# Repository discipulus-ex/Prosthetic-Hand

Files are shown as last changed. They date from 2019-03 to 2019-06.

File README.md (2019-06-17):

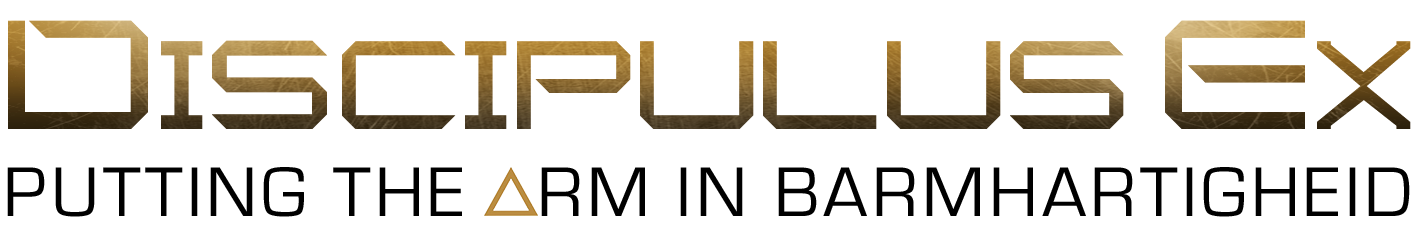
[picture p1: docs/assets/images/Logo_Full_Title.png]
Discipulus-Ex


# Discipulus-Ex: Prosthetic Hand
> A 3D-printed partial hand prosthesis using Arduino and OYMotion.

[The Prosthetic Hand:]()

---

## Table of Contents
- [Installation](#installation)
- [Features](#features)
- [Contributing](#contributing)
- [Team](#team)
- [Support](#support)
- [License](#license)

---

## Installation
Coming soon!

### Clone
Clone this repo to your local machine using:
```
$ git clone https://github.com/discipulus-ex/Prosthetic-Hand.git
```

---

## Features
Coming soon!

## Usage
Coming soon!

## Documentation
Coming soon!

---

## Contributing
### Step 1
- **Option 1**
  - Fork this repo!
- **Option 2**
  - Clone this repo to your local machine using:
    ```
    $ git clone https://github.com/discipulus-ex/Prosthetic-Hand.git
    ```
### Step 2
- **HACK AWAY!**

### Step 3
- Create a new pull request using <a href="https://github.com/discipulus-ex/Prosthetic-Hand/compare/" target="_blank">`https://github.com/discipulus-ex/Prosthetic-Hand/compare/`</a>

---

## Team
| <a href="https://discipulusex.nl/" target="_blank">**DDuunk**</a>  | <a href="https://discipulusex.nl/" target="_blank">**BeFunk**</a> | <a href="https://discipulusex.nl/" target="_blank">**Ghoris0127**</a> |
| :---: |:---:| :---:|
| DDuunk (https://discipulusex.nl/) | BeFunk (https://discipulusex.nl/) | Ghoris0127 (https://discipulusex.nl/) |
| <a href="http://github.com/DDuunk" target="_blank">`github.com/DDuunk`</a> | <a href="http://github.com/BeFunk" target="_blank">`github.com/BeFunk`</a> | <a href="https://github.com/Ghoris0127" target="_blank">`github.com/Ghoris0127`</a> |

---

## Support
Reach us out at:

- Website at <a href="https://discipulusex.nl/" target="_blank">`discipulusex.nl`</a>

---

## License


- **[MIT license](http://opensource.org/licenses/mit-license.php)**
- Copyright 2019 © <a href="https://discipulusex.nl/" target="_blank">Discipulus-Ex</a>.

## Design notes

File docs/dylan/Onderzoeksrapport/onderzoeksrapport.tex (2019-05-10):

\documentclass[11pt, a4paper]{article}
\usepackage[english]{babel}
\usepackage[utf8]{inputenc}
\usepackage{hyperref}
\usepackage{graphicx}
\usepackage{array}
\usepackage{enumitem}
\usepackage{pifont}
\usepackage{threeparttable}
\usepackage{amsmath}
\usepackage{booktabs}
\usepackage{fancyhdr}
\usepackage{pdflscape}

\renewcommand{\arraystretch}{1.5}

\graphicspath{ {./images/} }
\bibliographystyle{plain}

\title{ \Huge{Research report: \\ Prosthetic hand} \\ \vspace{1cm} \normalsize{\textit{First iteration}}} 
\author{Written by: \\ Dylan Duunk \textit{(0948392)} \\ \textit{Discipulus-Ex} 
\vspace{1cm} \\
Written for: \\ Ornella Schavemaker-Piva, \\ Wouter Volders \& \\ Nadine van Dormolen}
\vspace{1cm}
\date{12th April 2019}

\begin{document}

\begin{titlepage}
    \maketitle
\end{titlepage}

\pagenumbering{roman}

\newpage
 
\begin{abstract}
    \noindent
    Contemporary prostheses have advanced significantly the last few years.
    Previously, prostheses were quite expensive, nowadays one can 3D print a open-source prosthesis design.
    Unfortunately those designs are mostly made for below-elbow and above-elbow amputees.
    Our audience are people with a partial hand.
    With a partial hand prosthesis you also have to take the length of the user's arm in account.
    This makes it difficult to design prostheses for them.
    \\ \\
    So the research question is as follows: 
    \emph{
        \vspace{5pt}
        \begin{center}
            ``How to make an efficient design for a partial hand prosthesis and which parts are involved in making such a design?''
        \end{center}
        \vspace{5pt}
    }
    
    \noindent
    In this research report I will describe the different factors that play a role in making a prosthesis design, such as material choice and comfort.
    Furthermore I will describe the design I came up with.
\end{abstract}    

\newpage
\tableofcontents
\newpage
\pagenumbering{arabic}

\pagestyle{fancy}
\fancyhf{}
\rhead{Dylan Duunk}
\lhead{Research report: Prosthetic hand}
\rfoot{\thepage}

\section{Introduction}
Prostheses have advanced significantly in their functional capabilities and appearances over the past few years.
The latest trends in fabrication are elevating prosthetic comfort, function and appearance for thousands of prosthesis users.
But most of the higher-end prostheses are way to expensive for most people, while more and more people are eligible for prostheses.
\\ \\
With the latest technology of 3D printing and greater access to a 3D printer, the production of prostheses has become a lot easier and cheaper.
With the open source community of 3D printing, everyone with access to a 3D printer can make a prosthesis for themselves or for others.
\\ \\
Unfortunately for people with a partial hand, there are barely any designs for partial hand prostheses.
Most of these designs are body-powered prostheses or finger prostheses.
\\ \\
In this document, I will assess a variety of materials based on their suitability for prostheses whilst maintaining a comfortable fit and I show my design for a partial hand prosthesis and the idea behind it.

\section{Preliminary investigation}
One of the earliest records of a prosthetic hand was described n 77 AD by Roman scholar Pliny the Elder in his encyclopedia \textit{Naturalis Historia}\cite{natural_history}.
After losing a hand in the Second Punic War (218-201 BC), Marcus Sergius, a Roman general, received a prosthesis that enabled him to return successfully to battle and continue his position as a general.
\\ \\ 
Among the most famous example of an early hand prosthesis was the iron hand of German knight G\"otz von Berlichtingen \cite{historical_prostheses}.
After G\"otz lost his hand during the Siege of Landshut (circa 1505) in Bavaria, an artisan fashioned him an iron hand with digits that could be flexed and extended passively at finger joints (Figure \ref{fig:GotzProsthesis}).
Due to its weight, the device needed to be attached to G\"otz armour rather than his arm. 
\\
\begin{figure}[h]
    \centering
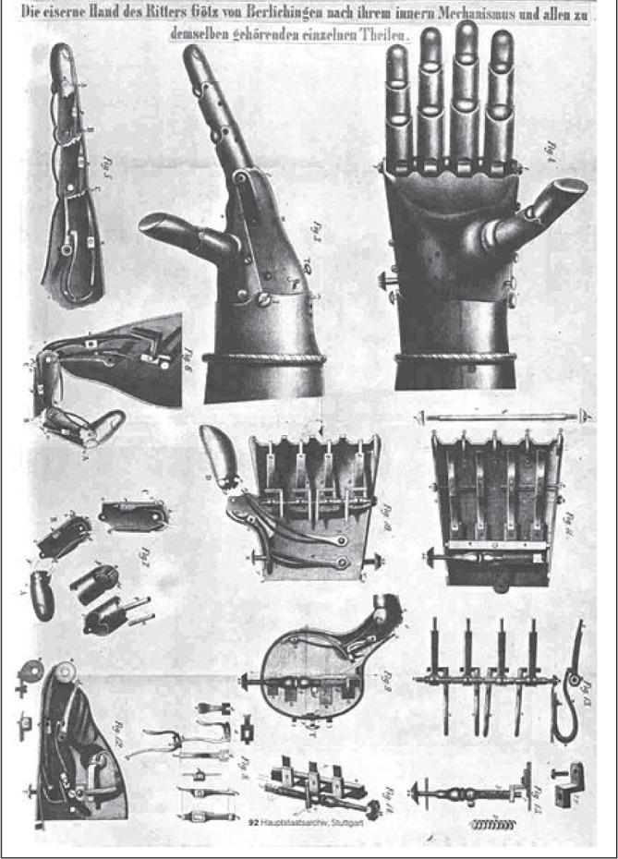
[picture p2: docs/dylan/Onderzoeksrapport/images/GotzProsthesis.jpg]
    
    \caption{Illustration of the numerous components of G\"otz's medieval hand prosthesis.}
    \label{fig:GotzProsthesis}
\end{figure}

\newpage

\noindent 
The concept of an body-powered upper limb prosthesis was pioneered by German dentist Peter Baliff in 1818 \cite{history_of_arm_amputation}.
Using transmission of tension through leather straps.
Baliff's device was opperated by the use of the trunk and shoulder girdle to elicit motion in the device.
\\ \\
In 1916, German surgeon Dr Ferdinand Sauerbruch described his prosthetic design with digits controlled by transmission of upper arm muscle movements (Figure \ref{fig:SauerbrunchProsthesis}) \cite{sauerbrunch}.
Unfortunately, due to the high cost of production, few individuals were able to afford the device.
\\
\begin{figure}[h]
    \centering
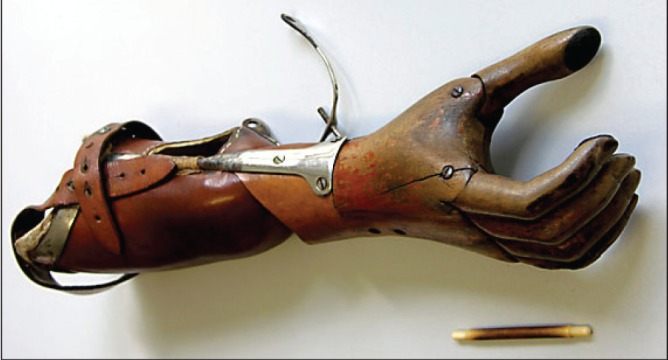
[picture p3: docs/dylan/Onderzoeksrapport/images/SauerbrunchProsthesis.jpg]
    
    \caption{Sauerbrunch's prosthetic hand design. Video captures of patients using the prosthesis to perform various activities may by viewed at \url{http://vlp.mpiwg-berlin.mpg.de/library/data/lit38416}}
    \label{fig:SauerbrunchProsthesis}
\end{figure} 

\noindent
In 1948, the Bowden cable body-powered prosthesis was introduced, replacing bulky straps with a sleek, sturdy cable.
Today's body-powered prostheses are essentially adaptations of the Bowden design (Figure \ref{fig:BowdenProsthesis}). 
Durable, portable and relatively affordable, body-powered prostheses allow the user an impressive range of motion, speed and force in operating a terminal device.
This design works by changing the tension in a cable via shoulder and body movements.
The design allows the ability to use both hands simultaneously, rather that requiring a healthy hand to control the prosthesis.
Furthermore, the user is able to predict and adjust the position of the prosthesis without visual feedback.
Although prolonged wearing can be uncomfortable, complicated motor tasks are limited and appearance is not human-like, body-powered prostheses are widely used.
\\
\begin{figure}[h]
    \centering
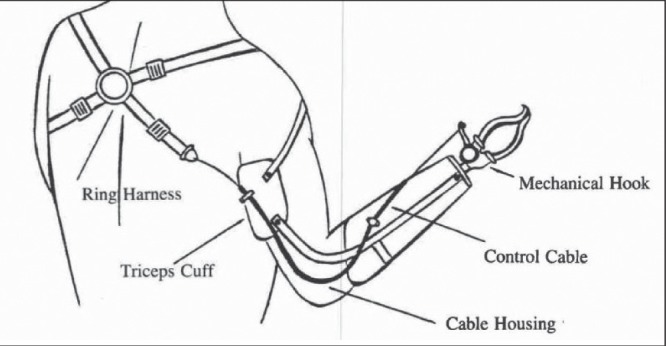
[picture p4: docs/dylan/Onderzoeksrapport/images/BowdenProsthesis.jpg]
    
    \caption{Bowden cable body powered prosthesis.}
    \label{fig:BowdenProsthesis}
\end{figure} 

\noindent
In 1919, a German book titled \textit{Ersatzglieder un Arbeitshilfen (Limb Substitutes and Work Aids)} contained conceptual designs for the first externally powered prostheses, using pneumatic and electric power sources (Figure \ref{fig:PrebluftHand}).
Unfortunately, these revolutionary designs were to complex for their time.
\\
\begin{figure}[h]
    \centering
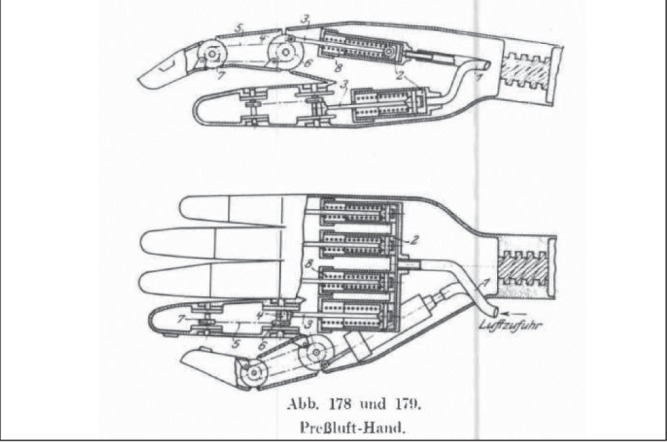
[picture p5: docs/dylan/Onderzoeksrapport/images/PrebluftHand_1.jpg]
    
    \caption{Early compressed gas-powered prosthetic hand from 1919 German book \textit{Ersatzglieder un Arbeitshilfen (Limb Substitutes and Work Aids)}.}
    \label{fig:PrebluftHand}
\end{figure} 

\noindent
The first myoelectric prosthesis was created in 1948 by Reinhold Reiter, a physics student at Munich University (Munich, Germany).
This device amplifies surface electromyography (EMG) potentials to power motorized parts.
\\ \\
The first clinically significant myoelectric prosthesis was unveiled by Russian scientist Alexander Kobrinski in 1960.
With the use of transistors he managed to reduce bulk and allowed portability of the prosthesis.
This prosthesis had numerous problems: it was heavy, movement was slow, pinch force was weak, wire connections were susceptible to damage and electrical interference compromised reliability \cite{myoelectric}.  

\newpage

\noindent
Nowadays myoelectric prostheses are a common option for amputees. 
They improved drastically in design, weight, power and cost.
In addition, signal detection is noninvasive on the skin surface and prosthetic movement is comparable with a normal limb.

\begin{figure}[h]
    \centering
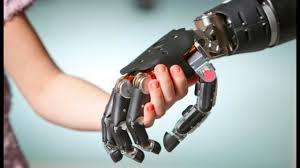
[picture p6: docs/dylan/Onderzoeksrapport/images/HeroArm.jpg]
    
    \caption{The Hero Arm, the world's first medically certified 3D-printed bionic arm, with multi-grip functionality and empowering aesthetics. \textit{Developed by OpenBionics} \url{https://openbionics.com/hero-arm/}}
    \label{fig:HeroArm}
\end{figure}    

\noindent
The problem with contemporary myoelectric prostheses is that they are primarily made for below-elbow and above-elbow amputees.
For our version we need to make a prosthetic hand for someone with a partial hand and therefore cannot use these common myoelectric prostheses.
So we need to come up with our own design.
\\ \\
This design needs to incorporate a lightweight material and has to be comfortable to use.

\section{Methodology}
My research consists of three parts: material, comfort and a prototype design incorporating the two previous aspects.
\\
These are my research methods for each part:
\begin{description}[align=left]
    \item[Material] Review a variety of commonly used materials for prostheses and compare them to each other.
    \item[Comfort] Research which factors play a role in comfort.
    \item[Prototype design] Experiment with various designs.
\end{description}    

\section{Results}
These are the results of my research:
\subsection{Materials} \label{materials}
Material choice plays a major role in prostheses.
Prostheses must be both strong and lightweight, they must be able to withstand the extensive use of the owner without obstructing there range of motion.
\\
Below I will review a variety of materials for our prosthetic hand.

\subsubsection{Plastic}
PLA and ABS are 2 of the most common FDM (Fused deposition modeling) desktop printing materials.
Both materials are thermoplastics, meaning they become pliable or moldable at a certain elevated temperature and solidifies upon cooling.
Via the FDM process, both materials are melted and then extruded trough a nozzle to build up the layers that create a final part.
\\ \\
Table \ref{tab:pla-abs} below compares the main properties between PLA \& ABS:

\begin{table}[ht]
    \centering
    \begin{threeparttable}
        \begin{tabular}[t]{>{\bfseries}l l l}
            \toprule
            Properties\tnote{1} & \textbf{PLA} & \textbf{ABS} \\
            \midrule
            Density & $1.3 g/cm^3$ & $1.0 - 1.4 g/cm^3$ \\
            Elongation & 6\% & 3.5-50\% \\ %https://en.wikipedia.org/wiki/Deformation_(mechanics)#Stretch_ratio
            Flexural Modulus & 4GPa & 2.1-7.6 GPa \\ %https://en.wikipedia.org/wiki/Flexural_modulus
            Melting Point & $160\,^{\circ}{\rm C}$ & N/A (amorphous) \\
            Biodegradable & Yes, under the correct conditions & No \\
            Glass Transition Temperature & $60\,^{\circ}{\rm C}$ & $105\,^{\circ}{\rm C}$ \\ %https://en.wikipedia.org/wiki/Glass_transition
            \bottomrule
        \end{tabular}
        \caption{Comparing PLA with ABS}
        \label{tab:pla-abs}
        \begin{tablenotes}
            \item[1] \textit{Sourced from MakeItFrom \cite{MakeItFrom}}
        \end{tablenotes}    
    \end{threeparttable}    
\end{table}

\subsubsection{Silicone}
Silicone is a dynamic material that moves with the body while simultaneously offering 
an enhanced grip on the residual limb and improved suspension of the prosthesis.
Silicone is mostly used in realistic looking prosthetics and for mold making.
\\ \\ 
Table \ref{tab:silicone-properties} below gives the main properties of silicone:

\begin{table}[ht]
    \centering
    \begin{threeparttable}
        \begin{tabular}[t]{>{\bfseries}l l}
            \toprule
            Properties\tnote{1} & \textbf{Silicone plastic}  \\
            \midrule
            Density & $1.9 g/cm^3$  \\
            Elastic Modulus & 9.0 GPa \\ %https://en.wikipedia.org/wiki/Elastic_modulus
            Max. Temperature: Decomposition & $480\,^{\circ}{\rm C}$  \\
            Biodegradable & No  \\
            Glass Transition Temperature & $200\,^{\circ}{\rm C}$  \\ %https://en.wikipedia.org/wiki/Glass_transition
            \bottomrule
        \end{tabular}
        \caption{Properties silicone plastic}
        \label{tab:silicone-properties}
        \begin{tablenotes}
            \item[1] \textit{Sourced from MakeItFrom \cite{MakeItFrom}}
        \end{tablenotes}    
    \end{threeparttable}    
\end{table}

\subsubsection{Carbon Fiber}
Carbon fiber reinforced plastic (CFRP), is an extremely strong and light fiber-reinforced plastic which contains carbon fibers.
Carbon fiber is often used in prosthetics, sports equipment, aerospace and wherever the high strength-to-weight ratio and stiffness from carbon fiber are required.
CFRPs are composite materials.
In this case the composite consists of two parts: a matrix and a reinforcement.
In this case the reinforcement is carbon fiber, which provides the strength.
The matix is usually a polymer resin, such as epoxy, to bind the reinforcements together.
This makes the material properties depend on those distinct elements.

\subsubsection{Metal}
Alloys containing titanium are known for their high strength, lightweight, and exceptional corrosion resistance.
Despite being as strong as steel, titanium is about 40\% lighter in weight.
Titanium is also formidable in its resistance to corrosion by both water and chemical media.
\\
Because titanium has a low modulus of elasticity that means titanium is not also very flexible, but returns to its original shape after bending.
\\ \\
Aluminium is a very light metal with a specific weight of $2.7 g/cm^3$, about a third that of steel.
Its strength can be adapted to the apllication required by modifying the composition of its alloys.
Aluminium naturally generates a protective oxide coating and is highly corrosion resistant which can be further imporeved by different types of surface treatments. 
This is particularly usefull for applications where protection and conservation are required.

\subsubsection{Morphological chart}

\begin{table}[ht]
    \centering
    \begin{threeparttable}
        \begin{tabular}[t]{>{\bfseries}l c c c c c c}
            \toprule
            & \textbf{PLA} & \textbf{ABS} & \textbf{Silicone} & \textbf{Carbon} & \textbf{Titanium\tnote{1}} & \textbf{Aluminium\tnote{1}}  \\
            \midrule
            Easy of use & \ding{72}\ding{72}\ding{72}\ding{72}\ding{72} & \ding{72}\ding{72}\ding{72}\ding{72}\ding{73} & \ding{72}\ding{72}\ding{72}\ding{73}\ding{73} & \ding{72}\ding{72}\ding{73}\ding{73}\ding{73} & \ding{72}\ding{73}\ding{73}\ding{73}\ding{73} & \ding{72}\ding{72}\ding{73}\ding{73}\ding{73} \\
            Strength & \ding{72}\ding{72}\ding{73}\ding{73}\ding{73} & \ding{72}\ding{72}\ding{72}\ding{73}\ding{73} & \ding{72}\ding{72}\ding{72}\ding{72}\ding{73} & \ding{72}\ding{72}\ding{72}\ding{72}\ding{72} & \ding{72}\ding{72}\ding{72}\ding{72}\ding{72} & \ding{72}\ding{72}\ding{72}\ding{72}\ding{72} \\
            Weight\tnote{2} & \ding{72}\ding{72}\ding{72}\ding{72}\ding{72} & \ding{72}\ding{72}\ding{72}\ding{72}\ding{72}  & \ding{72}\ding{72}\ding{72}\ding{72}\ding{72} & \ding{72}\ding{72}\ding{72}\ding{72}\ding{72} & \ding{72}\ding{72}\ding{72}\ding{72}\ding{72} & \ding{72}\ding{72}\ding{72}\ding{72}\ding{72}  \\
            Elastic Modulus & \ding{72}\ding{72}\ding{73}\ding{73}\ding{73} & \ding{72}\ding{72}\ding{72}\ding{73}\ding{73} & \ding{72}\ding{72}\ding{72}\ding{72}\ding{72} & \ding{72}\ding{72}\ding{72}\ding{73}\ding{73} & \ding{72}\ding{72}\ding{72}\ding{72}\ding{72} & \ding{72}\ding{72}\ding{72}\ding{73}\ding{73} \\
            Price & \ding{72}\ding{72}\ding{72}\ding{72}\ding{72} & \ding{72}\ding{72}\ding{72}\ding{72}\ding{72} & \ding{72}\ding{72}\ding{72}\ding{72}\ding{73} & \ding{72}\ding{72}\ding{73}\ding{73}\ding{73} & \ding{72}\ding{73}\ding{73}\ding{73}\ding{73} & \ding{72}\ding{72}\ding{72}\ding{73}\ding{73} \\
            Usability\tnote{3} & \ding{72}\ding{72}\ding{72}\ding{72}\ding{72} & \ding{72}\ding{72}\ding{72}\ding{72}\ding{73} & \ding{72}\ding{72}\ding{72}\ding{73}\ding{73} & \ding{72}\ding{73}\ding{73}\ding{73}\ding{73} & \ding{73}\ding{73}\ding{73}\ding{73}\ding{73} & \ding{72}\ding{73}\ding{73}\ding{73}\ding{73} \\
            \bottomrule
        \end{tabular}
        \caption{Materials Morphological Chart}
        \label{tab:morphchart-material}  
        \begin{tablenotes}
            \item[] These values in this Morphological Chart are based on eachother.
            \item[1] The material properties of these materials can vary based on the alloys used.
            \item[2] Weight is based on how lightweight the material is.
            \item[3] Usability in this case is based on how usefull this material will be for our prototype.  
        \end{tablenotes}    
    \end{threeparttable}   
\end{table}

\subsection{Comfort}
Comfort is an important factor for prostheses.
The prostheses must be an addition for the user, so that the user benefits of the prosthetic instead of being a chore.
Ideally the user shouldn't notice that a prosthesis is present.
This makes the user feel like a normal person and that the prosthesis is part of the body.
\\
Below I will describe which factors play a role in the comfort of prostheses.

\begin{description}[align=left]
    \item[Weight] The user must be able to wear the prosthesis for long periods of time in order to be usefull, this is why the prosthesis must be lightweight.
                  Otherwise the user has to carry the have load of the prosthesis and is therefore not sufficient.
    \item[Range of motion] The user must be able to have a relatively free range of motion, so that the user doesn't feel restricted.                       
    \item[Fit] The prosthesis must be securly fit to the user without impending the bloodflow.
               The fit shouldn't be to loose either, otherwise it will slip around all the time. 
    \item[Breathability] Because the user is wearing the prosthesis for longer periods of time, the user's skin needs to be able to freely breathe.   
    \item[Aesthetics] For some people the prosthesis my not stand out.
                      The attention some people get with a prosthesis may be annoing sometimes. 
\end{description}

\subsection{Prototype Design}
\textit{*Note: So far, the prototype only consists of the connection between my (Dylan) arm and a potential hand}

\subsubsection{First Prototype}
For the first prototype I wanted to make a casing for my forearm.
Because I didn't have access to a 3D scanner I had to come up with another solution to convert my drawings (Figure \ref{fig:ConceptPrototype1}) into a 3D model.
So I took measurements of my arm at different points, and seperated them into circles.
With these circles I moddeled around those circles in Fusion 360 and came up with this design (Figure \ref{fig:Prototype1Mechanical}). 
\\ \\
See table \ref{tab:FirstPrototypeProsCons} for the pros and cons of the first prototype.
\begin{table}[ht]
    \centering
    \begin{tabular}[t]{p{6cm} p{6cm}}
    \toprule
    \textbf{Pros} & \textbf{Cons} \\
    \midrule
    Thickness of the prototype is good. & For a someone with a partial hand this design is unneccessary bulky. \\
    & Design is more suitable for below-elbow amputees. \\
    & Fit was to small in diameter, which was solved by heating the prototype in hot water and reforming it. \\
    \bottomrule
    \end{tabular}
    \caption{First Prototype: Pros \& Cons}
    \label{tab:FirstPrototypeProsCons}
\end{table}

\begin{figure}[h]
    \centering
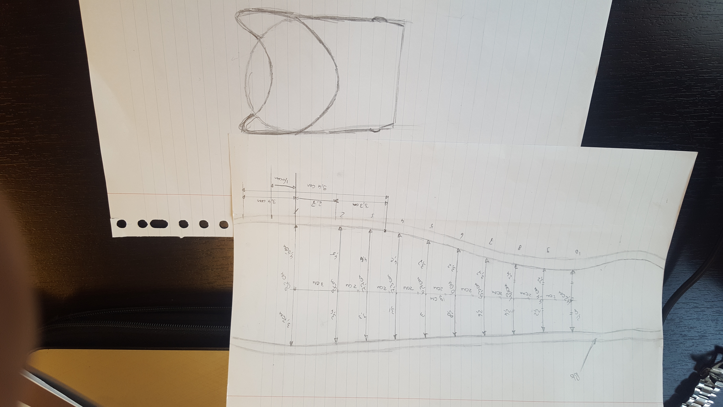
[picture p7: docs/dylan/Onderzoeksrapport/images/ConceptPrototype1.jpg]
    
    \caption{Concept drawings of the first prototype}
    \label{fig:ConceptPrototype1}
\end{figure} 

\newpage

\begin{landscape}
    \thispagestyle{empty}
    \begin{figure}[h]
        \centering
        
        \caption{Mechanical drawings for the first prototype. \textit{*Note: Measurements are mm!}}
        \label{fig:Prototype1Mechanical}
    \end{figure} 
\end{landscape}

\subsection{Second Prototype}
For the second prototype I wanted to make a casing specifically for my hand.
See figure \ref{fig:ConceptPrototype2} for my concept drawings. 
I moddeled around pictures of my hand in Fusion 360 and came up with this design (Figure \ref{fig:Prototype2Mechanical})
\\ \\
See table \ref{tab:SecondPrototypeProsCons} for the pros and cons of the second prototype.
\begin{table}[ht]
    \centering
    \begin{tabular}[t]{p{6cm} p{6cm}}
    \toprule
    \textbf{Pros} & \textbf{Cons} \\
    \midrule
    Thickness of the prototype is good. & Design is more suitable for users with a partial hand. \\
    Horizontal fit is good. & Vertical fit is in some places to loose. \\
    & Not designed for below-elbow and above-elbow amputees. \\ 
    \bottomrule
    \end{tabular}
    \caption{Second Prototype: Pros \& Cons}
    \label{tab:SecondPrototypeProsCons}
\end{table}

\begin{figure}[h]
    \centering
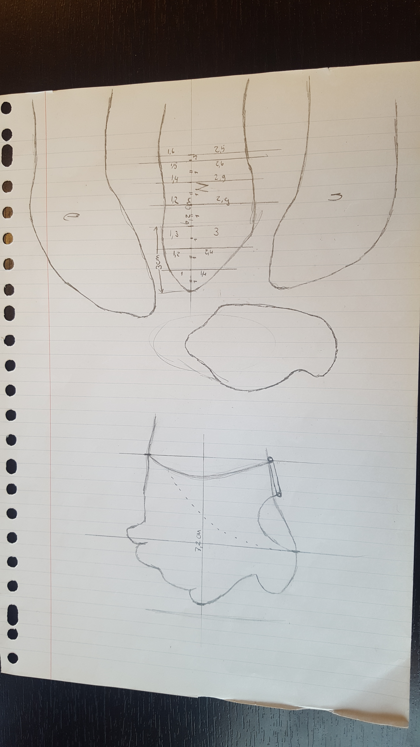
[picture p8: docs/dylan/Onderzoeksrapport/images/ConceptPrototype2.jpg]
    
    \caption{Concept drawings of the second prototype}
    \label{fig:ConceptPrototype2}
\end{figure} 

\newpage

\begin{landscape}
    \thispagestyle{empty}
    \begin{figure}[h]
        \centering
        
        \caption{Mechanical drawings for the second prototype. \textit{*Note: Some dimmensions could not be given and measurements are mm!}}
        \label{fig:Prototype2Mechanical}
    \end{figure} 
\end{landscape}

\subsection{Third Prototype}
For the third prototype I adjusted the fit of the second prototype and added a cutout so my hand could easily slide in .
I came up with this design (Figure \ref{fig:Prototype3Mechanical}).
\\ \\
See table \ref{tab:ThirdPrototypeProsCons} for the pros and cons of the third prototype.
\begin{table}[ht]
    \centering
    \begin{tabular}[t]{p{6cm} p{6cm}}
    \toprule
    \textbf{Pros} & \textbf{Cons} \\
    \midrule
    Thickness of the prototype is good. & A little cutout at the wrist would be nice. \\
    Fit is perfect. & Not designed for below-elbow and above-elbow amputees. \\ 
    No sharp edges. & \\
    Cutout is good. & \\
    \bottomrule
    \end{tabular}
    \caption{Third Prototype: Pros \& Cons}
    \label{tab:ThirdPrototypeProsCons}
\end{table}

\newpage

\begin{landscape}
    \thispagestyle{empty}
    \begin{figure}[h]
        \centering
        
        \caption{Mechanical drawings for the third prototype. \textit{*Note: Some dimmensions could not be given and measurements are mm!}}
        \label{fig:Prototype3Mechanical}
    \end{figure} 
\end{landscape}

\newpage

\section{Conclusion and advice}

\subsection{Material}
A combination of PLA, ABS and Silicone would be the best choice material wise. 
This is because PLA and ABS are easy to use for rapid prototyping, in a relatively short time we can put together a functional prototype.
When further developing this prototype to a product i suggest to look into replacing parts with stronger materials.
When it comes to silicone, silicone is very suitable for the grip pads.
These pads make it easier to pick up objects.

\subsection{Comfort}
These are my recommendations for improving the comfort of our prototype:
\begin{description}[align=left]
    \item[Weight] See section Materials \ref{materials} for my recommendation about materials and weight.
                  Another way to minimize weight is by using light weight electrical components. 
    \item[Range of motion] All moveable parts in the prototype should be able to move freely.
                           These parts shouldn't restrict the movements that the user has without the prosthesis.  
    \item[Fit] Make the prototype fit the users arm by giving a almost perfect fit.
    \item[Breathability] This is done by giving the part that fits the users arm some breathing holes, whilst not compromising structural integrity.
    \item[Aesthetics] This is done by keeping the design simple and modern.
\end{description}

\subsection{Prototype Design}
My recommendations for other amputees:
\textit{*Note: this does not include the general shape, because my hand isa different size.}
\begin{description}
    \item[Above-elbow] Extend the first prototype design to the upper arm.
                       Make sure the prototype can be rotated where the elbow would have been.
                       If the fit at the upper arm is not good enough maybe look into attaching the prototype to the shoulder.
    \item[Below-elbow] Extend the first prototype aswell.
                       If the fit at the lower arm is not good enough maybe look into attaching the prototype to the elbow/upper arm.
    \item[Other partial hands] For people with no fingers or "little stumps" see my recommendations for extending the current design below.
                               For people with some fingers extend the third design by cutting holes for the existing fingers.  
\end{description}

My recommendations for extending the current design are:
\begin{itemize}
    \item Extend the third prototype with a palm.
    \item Extend the palm with a connection to the fingers.
    \item Make an extension to the wrist for extra stability.
\end{itemize}

\clearpage
\addcontentsline{toc}{section}{References}
\bibliography{literature}

\end{document}

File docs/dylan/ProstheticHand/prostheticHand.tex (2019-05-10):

\documentclass[11pt, a4paper]{article}
\usepackage[english]{babel}
\usepackage[utf8]{inputenc}
\usepackage{hyperref}
\usepackage{graphicx}
\usepackage{array}
\usepackage{enumitem}
\usepackage{pifont}
\usepackage{threeparttable}
\usepackage{amsmath}
\usepackage{booktabs}
\usepackage{lipsum}

\renewcommand{\arraystretch}{1.5}

\graphicspath{ {./images/} }
\bibliographystyle{plain}

\title{\Huge{Prosthetic Hand} } 
\author{Dylan Duunk \\ \textit{Discipulus-Ex} }
\date{\today}

\begin{document}

\begin{titlepage}
    \maketitle
\end{titlepage}

\pagenumbering{roman}

% \newpage

% \begin{abstract}
%     \noindent 
%     \lipsum[1]
% \end{abstract}

\newpage
\tableofcontents
\newpage
\pagenumbering{arabic}

\section{Introduction}
Prostheses have advanced significantly in their functional capabilities and appearances over the past few years.
The latest trends in fabrication are elevating prosthetic comfort, function and appearance for thousands of prosthesis users.
But most of the higher-end prostheses are way to expensive for most people, and while more and more people are eligible for prosthesis.
\\ \\
With the latest technology of 3d printing and accessibility to a 3d printer, the production of prostheses has become a lot easier and cheaper.
With the open source community of 3d printing, everyone with access to a 3d printer can make a prosthetic for themselves.
\\ \\
In this document, I will assess a variety of materials based on their suitablility for prostheses whilst maintaining a comfortable fit. 

\section{Materials} \label{materials}
Material choice plays a major role in prostheses.
Prostheses must be both strong and lightweight, they must be able to withstand the extensive use of the owner without obstructing there range of motion.
\\
Below I will review a variety of materials for our prosthetic hand.

\subsection{Plastic}
PLA and ABS are 2 of the most common FDM (Fused deposition modeling) desktop printing materials.
Both materials are thermoplastics, meaning they become pliable or moldable at a certain elevated temperature and solidifies upon cooling.
Via the FDM process, both materials are melted and then extruded trough a nozzle to build up the layers that create a final part.
\\ \\
Table \ref{tab:pla-abs} below compares the main properties between PLA \& ABS:
\begin{table}[ht]
    \centering
    \begin{threeparttable}
        \begin{tabular}[t]{>{\bfseries}l l l}
            \toprule
            Properties\tnote{1} & \textbf{PLA} & \textbf{ABS} \\
            \midrule
            Density & $1.3 g/cm^3$ & $1.0 - 1.4 g/cm^3$ \\
            Elongation & 6\% & 3.5-50\% \\ %https://en.wikipedia.org/wiki/Deformation_(mechanics)#Stretch_ratio
            Flexural Modulus & 4GPa & 2.1-7.6 GPa \\ %https://en.wikipedia.org/wiki/Flexural_modulus
            Melting Point & $160\,^{\circ}{\rm C}$ & N/A (amorphous) \\
            Biodegradable & Yes, under the correct conditions & No \\
            Glass Transition Temperature & $60\,^{\circ}{\rm C}$ & $105\,^{\circ}{\rm C}$ \\ %https://en.wikipedia.org/wiki/Glass_transition
            \bottomrule
        \end{tabular}
        \caption{Comparing PLA with ABS}
        \label{tab:pla-abs}
        \begin{tablenotes}
            \item[1] \textit{Sourced from MakeItFrom \cite{MakeItFrom}}
        \end{tablenotes}    
    \end{threeparttable}    
\end{table}

\subsection{Silicone}
Silicone is a dynamic material that moves with the body while simultaneously offering 
an enhanced grip on the residual limb and improved suspension of the prosthesis.
Silicone is mostly used in realistic looking prosthetics and for mold making.
\\ \\ 
Table \ref{tab:silicone-properties} below gives the main properties of silicone:
\begin{table}[ht]
    \centering
    \begin{threeparttable}
        \begin{tabular}[t]{>{\bfseries}l l}
            \toprule
            Properties\tnote{1} & \textbf{Silicone plastic}  \\
            \midrule
            Density & $1.9 g/cm^3$  \\
            Elastic Modulus & 9.0 GPa \\ %https://en.wikipedia.org/wiki/Elastic_modulus
            Max. Temperature: Decomposition & $480\,^{\circ}{\rm C}$  \\
            Biodegradable & No  \\
            Glass Transition Temperature & $200\,^{\circ}{\rm C}$  \\ %https://en.wikipedia.org/wiki/Glass_transition
            \bottomrule
        \end{tabular}
        \caption{Properties silicone plastic}
        \label{tab:silicone-properties}
        \begin{tablenotes}
            \item[1] \textit{Sourced from MakeItFrom \cite{MakeItFrom}}
        \end{tablenotes}    
    \end{threeparttable}    
\end{table}

\subsection{Carbon Fiber}
Carbon fiber reinforced plastic (CFRP), is an extremely strong and light fiber-reinforced plastic which contains carbon fibers.
Carbon fiber is often used in prosthetics, sports equipment, aerospace and wherever the high strength-to-weight ratio and stiffness from carbon fiber are required.
CFRPs are composite materials.
In this case the composite consists of two parts: a matrix and a reinforcement.
In this case the reinforcement is carbon fiber, which provides the strength.
The matix is usually a polymer resin, such as epoxy, to bind the reinforcements together.
This makes the material properties depend on those distinct elements.

\subsection{Metal}
Alloys containing titanium are known for their high strength, lightweight, and exceptional corrosion resistance.
Despite being as strong as steel, titanium is about 40\% lighter in weight.
Titanium is also formidable in its resistance to corrosion by both water and chemical media.
\\
Because titanium has a low modulus of elasticity that means titanium is not also very flexible, but returns to its original shape after bending.
\\ \\
Aluminium is a very light metal with a specific weight of $2.7 g/cm^3$, about a third that of steel.
Its strength can be adapted to the apllication required by modifying the composition of its alloys.
Aluminium naturally generates a protective oxide coating and is highly corrosion resistant which can be further imporeved by different types of surface treatments. 
This is particularly usefull for applications where protection and conservation are required.

\subsection{Morphological chart}
% 0 stars 
% \ding{73}\ding{73}\ding{73}\ding{73}\ding{73}
% 1 stars 
% \ding{72}\ding{73}\ding{73}\ding{73}\ding{73} 
% 2 stars 
% \ding{72}\ding{72}\ding{73}\ding{73}\ding{73}
% 3 stars 
% \ding{72}\ding{72}\ding{72}\ding{73}\ding{73}
% 4 stars 
% \ding{72}\ding{72}\ding{72}\ding{72}\ding{73}
% 5 stars 
% \ding{72}\ding{72}\ding{72}\ding{72}\ding{72} 
\begin{table}[ht]
    \centering
    \begin{threeparttable}
        \begin{tabular}[t]{>{\bfseries}l c c c c c c}
            \toprule
            & \textbf{PLA} & \textbf{ABS} & \textbf{Silicone} & \textbf{Carbon} & \textbf{Titanium\tnote{1}} & \textbf{Aluminium\tnote{1}}  \\
            \midrule
            Easy of use & \ding{72}\ding{72}\ding{72}\ding{72}\ding{72} & \ding{72}\ding{72}\ding{72}\ding{72}\ding{73} & \ding{72}\ding{72}\ding{72}\ding{73}\ding{73} & \ding{72}\ding{72}\ding{73}\ding{73}\ding{73} & \ding{72}\ding{73}\ding{73}\ding{73}\ding{73} & \ding{72}\ding{72}\ding{73}\ding{73}\ding{73} \\
            Strength & \ding{72}\ding{72}\ding{73}\ding{73}\ding{73} & \ding{72}\ding{72}\ding{72}\ding{73}\ding{73} & \ding{72}\ding{72}\ding{72}\ding{72}\ding{73} & \ding{72}\ding{72}\ding{72}\ding{72}\ding{72} & \ding{72}\ding{72}\ding{72}\ding{72}\ding{72} & \ding{72}\ding{72}\ding{72}\ding{72}\ding{72} \\
            Weight\tnote{2} & \ding{72}\ding{72}\ding{72}\ding{72}\ding{72} & \ding{72}\ding{72}\ding{72}\ding{72}\ding{72}  & \ding{72}\ding{72}\ding{72}\ding{72}\ding{72} & \ding{72}\ding{72}\ding{72}\ding{72}\ding{72} & \ding{72}\ding{72}\ding{72}\ding{72}\ding{72} & \ding{72}\ding{72}\ding{72}\ding{72}\ding{72}  \\
            Elastic Modulus & \ding{72}\ding{72}\ding{73}\ding{73}\ding{73} & \ding{72}\ding{72}\ding{72}\ding{73}\ding{73} & \ding{72}\ding{72}\ding{72}\ding{72}\ding{72} & \ding{72}\ding{72}\ding{72}\ding{73}\ding{73} & \ding{72}\ding{72}\ding{72}\ding{72}\ding{72} & \ding{72}\ding{72}\ding{72}\ding{73}\ding{73} \\
            Price & \ding{72}\ding{72}\ding{72}\ding{72}\ding{72} & \ding{72}\ding{72}\ding{72}\ding{72}\ding{72} & \ding{72}\ding{72}\ding{72}\ding{72}\ding{73} & \ding{72}\ding{72}\ding{73}\ding{73}\ding{73} & \ding{72}\ding{73}\ding{73}\ding{73}\ding{73} & \ding{72}\ding{72}\ding{72}\ding{73}\ding{73} \\
            Usability\tnote{3} & \ding{72}\ding{72}\ding{72}\ding{72}\ding{72} & \ding{72}\ding{72}\ding{72}\ding{72}\ding{73} & \ding{72}\ding{72}\ding{72}\ding{73}\ding{73} & \ding{72}\ding{73}\ding{73}\ding{73}\ding{73} & \ding{73}\ding{73}\ding{73}\ding{73}\ding{73} & \ding{72}\ding{73}\ding{73}\ding{73}\ding{73} \\
            \bottomrule
        \end{tabular}
        \caption{Materials Morphological Chart}
        \label{tab:morphchart-material}  
        \begin{tablenotes}
            \item[] These values in this Morphological Chart are based on eachother.
            \item[1] The material properties of these materials can vary based on the alloys used.
            \item[2] Weight is based on how lightweight the material is.
            \item[3] Usability in this case is based on how usefull this material will be for our prototype.  
        \end{tablenotes}    
    \end{threeparttable}   
\end{table}

\subsection{Conclusion}
A combination of PLA, ABS and Silicone would be the best choice material wise. 
This is because PLA and ABS are easy to use for rapid prototyping, in a relatively short time we can put together a functional prototype.
When further developing this prototype to a product i suggest to look into replacing parts with stronger materials.
When it comes to silicone, silicone is very suitable for the grip pads.
These pads make it easier to pick up objects.

\section{Comfort}
Comfort is an important factor for prostheses.
The prostheses must be an addition for the user, so that the user benefits of the prosthetic instead of being a chore.
Ideally the user shouldn't notice that a prosthesis is present.
This makes the user feel like a normal person and that the prosthesis is part of the body.
\\
Below I will describe which factors play a role in the comfort of prostheses.

\begin{description}[align=left]
    \item[Weight] The user must be able to wear the prosthesis for long periods of time in order to be usefull, this is why the prosthesis must be lightweight.
                  Otherwise the user has to carry the have load of the prosthesis and is therefore not sufficient.
    \item[Range of motion] The user must be able to have a relatively free range of motion, so that the user doesn't feel restricted.                       
    \item[Fit] The prosthesis must be securly fit to the user without impending the bloodflow.
               The fit shouldn't be to loose either, otherwise it will slip around all the time. 
    \item[Breathability] Because the user is wearing the prosthesis for longer periods of time, the user's skin needs to be able to freely breathe.   
\end{description}

\subsection{Conclusion}
These are my recommendations for improving the comfort of our prototype:
\begin{description}[align=left]
    \item[Weight] See section Materials \ref{materials} for my recommendation about materials and weight.
                  Another way to minimize weight is by using light weight electrical components. 
    \item[Range of motion] All moveable parts in the prototype should be able to move freely.
                           These parts shouldn't restrict the movements that the user has without the prosthesis.  
    \item[Fit] Make the prototype fit the users arm by giving a almost perfect fit.
    \item[Breathability] This is done by giving the part that fits the users arm some breathing holes, whilst not compromising structural integrity.
\end{description}

\newpage

\bibliography{literature}

\end{document}

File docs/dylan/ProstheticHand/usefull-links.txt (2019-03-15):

https://opedge.com/Articles/ViewArticle/2016-07_02
https://www.prescouter.com/2017/07/3d-printed-prosthetics/
https://all3dp.com/2/the-most-common-3d-printed-prosthetics/
https://www.makeitfrom.com/

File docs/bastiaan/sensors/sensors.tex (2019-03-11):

\documentclass[11pt,a4paper]{article}

\usepackage[utf8]{inputenc}
\usepackage[T1]{fontenc}
\usepackage[english]{babel}

\usepackage[margin=1.0in]{geometry}
\usepackage[parfill]{parskip}
\tolerance=1000
\hyphenpenalty=1000
%\hbadness=10000
%\widowpenalties=1 10000
%\raggedbottom

\usepackage[bookmarks]{hyperref}
\usepackage[defernumbers,sortcites,sorting=none]{biblatex}
%\usepackage{blindtext}
\usepackage{booktabs}
\usepackage{pifont}
%\usepackage{enumitem}
%\usepackage{graphicx, wrapfig}
%\usepackage{mathtools}
%\usepackage{subcaption}
%\usepackage{textcomp}

\usepackage{cochineal}
\usepackage[varqu,varl,var0]{zi4} % Inconsolata
\usepackage[scale=.95,type1]{cabin}
\usepackage[cochineal,bigdelims,cmintegrals,vvarbb]{newtxmath}
\usepackage[cal=boondoxo]{mathalfa}

\title{Research on sensors}
\author{Bastiaan Teeuwen (0945334) --- Discipulus Ex}
\date{\today}

\addbibresource{bibliography.bib}

\begin{document}

\maketitle

In this document, I will review a variety of sensors that we could use to get
input for our prosthetic hand.

\section{Muscle sensors}
One possibility would be to use muscle sensors, also called electromyography
(EMG), to record electrical activity produced by the muscles. Electrodes would
be placed on one's upper arm or forearm. An EMG device would be used to detect
the level of activation of certain muscles.~\cite{emg}

A quick Internet search reveals that muscle sensors are relatively easy to
acquire and interface with. Take the
\href{https://www.sparkfun.com/products/13723}{MyoWare Muscle Sensor} for
example. The only interfacing device required is an Arduino to read out the
voltage levels.

Various studies have been done on using EMGs to capture finger movement. In one
study, four electrodes were placed on the forearm after which various finger
motions were performed. The data was fed into and EMG and after a 25 training
sessions the finger motions could be precisely registered. The results are
pretty stunning with a reported accuracy of 97.75\%.~\cite{decoding}\\
The question is whether this will still work when the patient is missing his or
her fingers.

\section{Brainwave sensors}
A brainwave sensor, also called electroencephalography (EEG) is a method of
monitoring electrical brainwave activity. The idea is that electrodes are placed
on one's skull after which the EEG device will record the various known brain
waves.~\cite{eeg} Let's look at the various types of brainwaves to see if
they're of any use to us.

EEG devices are relatively more expensive and not as easy to interface with as
EMGs.~\cite{eegbuy}

\subsection{Delta wave}
First, we have the $\delta$ (delta) wave, which is commonly used to analyse
one's sleep pattern.~\cite{delta}

\subsection{Theta wave}
Then we have the $\theta$ (theta) wave, which can be linked to whether one is in
an idle state or performing a certain task. It is also related to motor behavior
as a result of sensory stimuli.~\cite{theta}

\subsection{Alpha wave}
The $\alpha$ (alpha) wave, just like the Delta wave, is linked to sleep activity
as well. It can also be weakly linked to the Visual cortex which is a part of
the brain that processes visual information.~\cite{alpha}

\subsection{Beta wave}
The $\beta$ (beta) wave is associated with various different state of
consciousness like flow, relaxation, anxiety, and so on.~\cite{flow}
Furthermore, this brain wave is also associated with isotonic (static) muscle
contractions, meaning the contraction of muscles without movement (like when
performing pushups or lat pulldowns~\cite{isotonic}).~\cite{beta}

\subsection{Gamma wave}
No much is known about the $\gamma$ (gamma) wave, other than that it is possibly
related to consciousness.~\cite{gamma}

\subsection{Mu wave}
The final distinguishable brain wave is the $\mu$ (mu) wave. The Mu wave is most
prominent in the Motor cortex, a part of the brain which controls coordinated
movements. Besides actual motor movement, intention of movement can also be
traced back to the Mu wave. This is especially of interest to people who are
missing a certain body part. One would be able to visualize a movement and this
could (with enough training) be registered as a Mu wave on an EEG
device.~\cite{mu}

\subsection{Conclusion}
The $\theta$ (theta) wave could possibly be of interest to us as it is related
to motor movement. But the $\mu$ (mu) wave would probably be of greater interest
to us as it can be strongly linked to motor activity and intention of motor
activity regardless of stimuli.
We could look for a pattern in both of these waves relating to the muscle
movement in the hand or fingers.

\section{Morphological chart}

\begin{center}
\begin{tabular}{l c c}
	& EMG & EEG\\
	\midrule
	Ease of use & \ding{72}\ding{72}\ding{72}\ding{72}\ding{73} & \ding{72}\ding{72}\ding{73}\ding{73}\ding{73}\\
	Observability & \ding{72}\ding{72}\ding{72}\ding{72}\ding{73} & \ding{72}\ding{72}\ding{72}\ding{73}\ding{73}\\
	Intention observability & \ding{73}\ding{73}\ding{73}\ding{73}\ding{73} & \ding{72}\ding{72}\ding{72}\ding{72}\ding{73}\\
	Research & \ding{72}\ding{72}\ding{72}\ding{72}\ding{73} & \ding{72}\ding{72}\ding{72}\ding{73}\ding{73}\\
	Interfacing & \ding{72}\ding{72}\ding{72}\ding{72}\ding{73} & \ding{72}\ding{72}\ding{72}\ding{73}\ding{73}\\
	Price & \ding{72}\ding{72}\ding{72}\ding{72}\ding{73} & \ding{72}\ding{72}\ding{73}\ding{73}\ding{73}\\
	\bottomrule
\end{tabular}
\end{center}

\section{Conclusion}
An advantage of using electroencephalography over electromyography is that the
brainwaves for controlling a body part are always detectable even if a patient
is missing that body part. The advantage of using an EMG is that they're
easier to work with as less decoding is required and less noise is present.
Furthermore, more research has been done on using EMGs for prosthetic
applications.~\cite{emg}

I would recommend we try the EMG first and only try using the EEG if we are
unable to register movement in patients with missing fingers.

\newpage
\printbibliography{}

\end{document}

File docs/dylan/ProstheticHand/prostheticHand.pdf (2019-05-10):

# Prosthetic Hand

Dylan Duunk

Discipulus-Ex

April 11, 2019

1

## Contents

1 Introduction | 1
2 Materials | 1
3 Comfort | 4

i

## 1 Introduction

Prostheses have advanced significantly in their functional capabilities and appearances over the past few years. The latest trends in fabrication are elevating prosthetic comfort, function and appearance for thousands of prosthesis users. But most of the higher-end prostheses are way to expensive for most people, and while more and more people are eligible for prosthesis.

With the latest technology of 3d printing and accessibility to a 3d printer, the production of prostheses has become a lot easier and cheaper. With the open source community of 3d printing, everyone with access to a 3d printer can make a prosthetic for themselves.

In this document, I will assess a variety of materials based on their suitablility for prostheses whilst maintaining a comfortable fit.

## 2 Materials

Material choice plays a major role in prostheses. Prostheses must be both strong and lightweight, they must be able to withstand the extensive use of the owner without obstructing there range of motion.
Below I will review a variety of materials for our prosthetic hand.

### 2.1 Plastic

PLA and ABS are 2 of the most common FDM (Fused deposition modeling) desktop printing materials. Both materials are thermoplastics, meaning they become pliable or moldable at a certain elevated temperature and solidifies upon cooling. Via the FDM process, both materials are melted and then extruded trough a nozzle to build up the layers that create a final part.

Table 1 below compares the main properties between PLA & ABS:

### 2.2 Silicone

Silicone is a dynamic material that moves with the body while simultaneously offering an enhanced grip on the residual limb and improved suspension of the prosthesis. Silicone is mostly used in realistic looking prosthetics and for mold making.

Table 2 below gives the main properties of silicone:

1

Properties¹ | PLA | ABS
Density | 1.3g/cm³ | 1.0 − 1.4g/cm³
Elongation | 6% | 3.5-50%
Flexural Modulus | 4GPa | 2.1-7.6 GPa
Melting Point | 160 ◦C | N/A (amorphous)
Biodegradable | Yes, under the correct conditions | No
Glass Transition Temperature | 60 ◦C | 105 ◦C

Table 1: Comparing PLA with ABS 1 Sourced from MakeItFrom [1]

Properties¹ | Silicone plastic
Density | 1.9g/cm³
Elastic Modulus | 9.0 GPa
Max. Temperature: Decomposition | 480 ◦C
Biodegradable | No
Glass Transition Temperature | 200 ◦C

Table 2: Properties silicone plastic 1 Sourced from MakeItFrom [1]

### 2.3 Carbon Fiber

Carbon fiber reinforced plastic (CFRP), is an extremely strong and light fiber-reinforced plastic which contains carbon fibers. Carbon fiber is often used in prosthetics, sports equipment, aerospace and wherever the high strength-to-weight ratio and stiffness from carbon fiber are required. CFRPs are composite materials. In this case the composite consists of two parts: a matrix and a reinforcement. In this case the reinforcement is carbon fiber, which provides the strength. The matix is usually a polymer resin, such as epoxy, to bind the reinforcements together. This makes the material properties depend on those distinct elements.

2

### 2.4 Metal

Alloys containing titanium are known for their high strength, lightweight, and exceptional corrosion resistance. Despite being as strong as steel, titanium is about 40% lighter in weight. Titanium is also formidable in its resistance to corrosion by both water and chemical media.
Because titanium has a low modulus of elasticity that means titanium is not also very flexible, but returns to its original shape after bending.

Aluminium is a very light metal with a specific weight of 2.7g/cm³
, about
a third that of steel. Its strength can be adapted to the apllication required by modifying the composition of its alloys. Aluminium naturally generates a protective oxide coating and is highly corrosion resistant which can be further imporeved by different types of surface treatments. This is particularly usefull for applications where protection and conservation are required.

### 2.5 Morphological chart

PLA | ABS | Silicone | Carbon | Titanium¹ Aluminium¹
Easy of use | ★★★★★ | ★★★★✩ | ★★★✩✩ | ★★✩✩✩ | ★✩✩✩✩ | ★★✩✩✩
Strength | ★★✩✩✩ | ★★★✩✩ | ★★★★✩ | ★★★★★ | ★★★★★ | ★★★★★
Weight² | ★★★★★ | ★★★★★ | ★★★★★ | ★★★★★ | ★★★★★ | ★★★★★
Elastic Modulus | ★★✩✩✩ | ★★★✩✩ | ★★★★★ | ★★★✩✩ | ★★★★★ | ★★★✩✩
Price | ★★★★★ | ★★★★★ | ★★★★✩ | ★★✩✩✩ | ★✩✩✩✩ | ★★★✩✩
Usability³ | ★★★★★ | ★★★★✩ | ★★★✩✩ | ★✩✩✩✩ | ✩✩✩✩✩ | ★✩✩✩✩

Table 3: Materials Morphological Chart

These values in this Morphological Chart are based on eachother.
1 The material properties of these materials can vary based on the alloys used.
2 Weight is based on how lightweight the material is.
3 Usability in this case is based on how usefull this material will be for our prototype.

### 2.6 Conclusion

A combination of PLA, ABS and Silicone would be the best choice material wise. This is because PLA and ABS are easy to use for rapid prototyping, in a relatively short time we can put together a functional prototype. When further developing this prototype to a product i suggest to look into replacing

3

parts with stronger materials. When it comes to silicone, silicone is very suitable for the grip pads. These pads make it easier to pick up objects.

## 3 Comfort

Comfort is an important factor for prostheses. The prostheses must be an addition for the user, so that the user benefits of the prosthetic instead of being a chore. Ideally the user shouldn’t notice that a prosthesis is present. This makes the user feel like a normal person and that the prosthesis is part of the body.
Below I will describe which factors play a role in the comfort of prostheses.

Weight The user must be able to wear the prosthesis for long periods of time in order to be usefull, this is why the prosthesis must be lightweight. Otherwise the user has to carry the have load of the prosthesis and is therefore not sufficient.

Range of motion The user must be able to have a relatively free range of motion, so that the user doesn’t feel restricted.

Fit The prosthesis must be securly fit to the user without impending the bloodflow. The fit shouldn’t be to loose either, otherwise it will slip around all the time.

Breathability Because the user is wearing the prosthesis for longer periods of time, the user’s skin needs to be able to freely breathe.

### 3.1 Conclusion

These are my recommendations for improving the comfort of our prototype:

Weight See section Materials 2 for my recommendation about materials and weight. Another way to minimize weight is by using light weight electrical components.

Range of motion All moveable parts in the prototype should be able to move freely. These parts shouldn’t restrict the movements that the user has without the prosthesis.

Fit Make the prototype fit the users arm by giving a almost perfect fit.

Breathability This is done by giving the part that fits the users arm some breathing holes, whilst not compromising structural integrity.

4

## References

[1] MakeItFrom. Material properties database. Available at https://www.makeitfrom.com/, 2009.

5

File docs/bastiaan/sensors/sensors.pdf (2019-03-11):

## Research on sensors

Bastiaan Teeuwen (0945334) — Discipulus Ex

## March 11, 2019

In this document, I will review a variety of sensors that we could use to get input for our prosthetic

hand.

# 1 Muscle sensors

One possibility would be to use muscle sensors, also called electromyography (EMG), to record electrical

activity produced by the muscles. Electrodes would be placed on one’s upper arm or forearm. An EMG

device would be used to detect the level of activation of certain muscles. [1]

A quick Internet search reveals that muscle sensors are relatively easy to acquire and interface with. Take

the MyoWare Muscle Sensor (https://www.sparkfun.com/products/13723) for example. The only interfacing device required is an Arduino to read out

the voltage levels.

Various studies have been done on using EMGs to capture finger movement. In one study, four electrodes

were placed on the forearm after which various finger motions were performed. The data was fed into

and EMG and after a 25 training sessions the finger motions could be precisely registered. The results are

pretty stunning with a reported accuracy of 97.75%. [2]

The question is whether this will still work when the patient is missing his or her fingers.

# 2 Brainwave sensors

A brainwave sensor, also called electroencephalography (EEG) is a method of monitoring electrical

brainwave activity. The idea is that electrodes are placed on one’s skull after which the EEG device will

record the various known brain waves. [3] Let’s look at the various types of brainwaves to see if they’re of

any use to us.

EEG devices are relatively more expensive and not as easy to interface with as EMGs. [4]

# 2.1 Delta wave

First, we have the δ (delta) wave, which is commonly used to analyse one’s sleep pattern. [5]

# 2.2 Theta wave

Then we have the θ (theta) wave, which can be linked to whether one is in an idle state or performing a

certain task. It is also related to motor behavior as a result of sensory stimuli. [6]

# 2.3 Alpha wave

The α (alpha) wave, just like the Delta wave, is linked to sleep activity as well. It can also be weakly linked

to the Visual cortex which is a part of the brain that processes visual information. [7]

# 2.4 Beta wave

The β (beta) wave is associated with various different state of consciousness like flow, relaxation, anxiety,

and so on. [8] Furthermore, this brain wave is also associated with isotonic (static) muscle contractions,

meaning the contraction of muscles without movement (like when performing pushups or lat pull-

downs [9]). [10]

# 2.5 Gamma wave

No much is known about the γ (gamma) wave, other than that it is possibly related to conscious-

ness. [11]

# 2.6 Mu wave

The final distinguishable brain wave is the μ (mu) wave. The Mu wave is most prominent in the Motor

cortex, a part of the brain which controls coordinated movements. Besides actual motor movement,

intention of movement can also be traced back to the Mu wave. This is especially of interest to people

who are missing a certain body part. One would be able to visualize a movement and this could (with

enough training) be registered as a Mu wave on an EEG device. [12]

# 2.7 Conclusion

The θ (theta) wave could possibly be of interest to us as it is related to motor movement. But the μ (mu)

wave would probably be of greater interest to us as it can be strongly linked to motor activity and intention

of motor activity regardless of stimuli. We could look for a pattern in both of these waves relating to the

muscle movement in the hand or fingers.

# 3 Morphological chart

| EMG | EEG
Ease of use | ★★★★✩ | ★★✩✩✩
Observability | ★★★★✩ | ★★★✩✩
Intention observability | ✩✩✩✩✩ | ★★★★✩
Research | ★★★★✩ | ★★★✩✩
Interfacing | ★★★★✩ | ★★★✩✩
Price | ★★★★✩ | ★★✩✩✩

# 4 Conclusion

An advantage of using electroencephalography over electromyography is that the brainwaves for control-

ling a body part are always detectable even if a patient is missing that body part. The advantage of using an

EMG is that they’re easier to work with as less decoding is required and less noise is present. Furthermore,

more research has been done on using EMGs for prosthetic applications. [1]

I would recommend we try the EMG first and only try using the EEG if we are unable to register movement

in patients with missing fingers.

# References

[1] Electromyography. url: https://en.wikipedia.org/wiki/Electromyography.
[2] Finger Motion Decoding Using EMG Signals Corresponding Various Arm Postures. url: https://www.ncbi.nlm.nih.gov/pmc/articles/PMC3214794/.
[3] What are Brainwaves? url: https://brainworksneurotherapy.com/what-are-brainwaves.
[4] EEG Headset Prices – An Overview of 15+ EEG Devices. url: https://imotions.com/blog/eeg-

# headset-prices/. (https://imotions.com/blog/eeg-headset-prices/)

[5] Delta wave. url: https://en.wikipedia.org/wiki/Delta_wave.
[6] Theta wave. url: https://en.wikipedia.org/wiki/Theta_wave.
[7] Alpha wave. url: https://en.wikipedia.org/wiki/Alpha_wave.
[8] Flow (psychology). url: https://en.wikipedia.org/wiki/Flow_(psychology)#Conditions.
[9] Isotonic Vs. Isometric Contraction. url: https://healthyliving.azcentral.com/isotonic-vsisometric-contraction-10419.html. (https://healthyliving.azcentral.com/isotonic-vs-isometric-contraction-10419.html)
[10] Beta wave. url: https://en.wikipedia.org/wiki/Beta_wave.
[11] Gamma wave. url: https://en.wikipedia.org/wiki/Gamma_wave.
[12] Mu wave. url: https://en.wikipedia.org/wiki/Mu_wave.

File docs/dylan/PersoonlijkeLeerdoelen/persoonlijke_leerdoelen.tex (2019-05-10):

\documentclass[12pt, a4paper]{article}
\usepackage[english]{babel}
\usepackage[utf8]{inputenc}
\usepackage{graphicx}
\usepackage{amsmath}
\usepackage{hyperref}
\usepackage{physics}
\usepackage{array}
\usepackage{booktabs}
\usepackage{enumitem}

\graphicspath{ {./images/} }

\title{\Huge{Personal Learning Objectives} }
\author{Dylan Duunk \\ \textit{(0948392)}}
\date{\today}

\begin{document}

\maketitle

\noindent
In this document, I will describe my personal learning objectives.

\section*{Personal learning objectives}

\begin{description}[align=left]
    \item[3D Modeling] For the prototyping process is 3d modeling a very usefull skill to have.
                       I want to improve my 3d modeling skills by making use of an advanced CAD program like Fusion 360.
                       Fusion 360 is quite difficult program to use without any knowledge, but can be a very usefull tool.
                       For example, the functions that Fusion 360 offers make the designing of complex shapes a lot easier.
                       This can be a chore in simpler CAD programs like Tinkercad.
    \item[Version Control] Version control can be a very handy tool for development.
                           I want to learn how to make efficient use of version control and make it a habit to use version control.
    \item[Prototyping] I want to improve my ability to efficiently prototype by designing multiple iterations to make create a fully-fledged product. 
\end{description}   

\end{document}

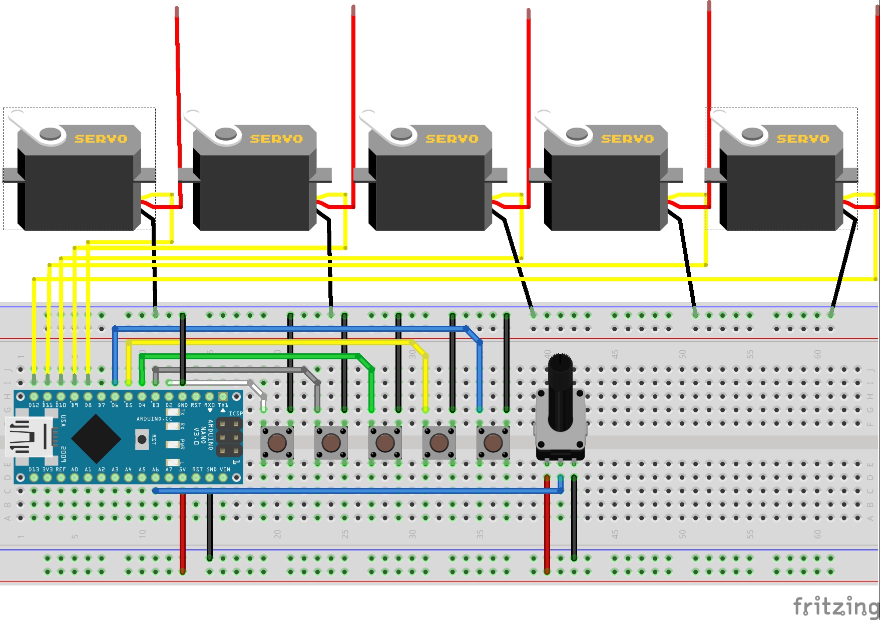
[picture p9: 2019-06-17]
docs/dylan/assets/Hardware_bb.jpg

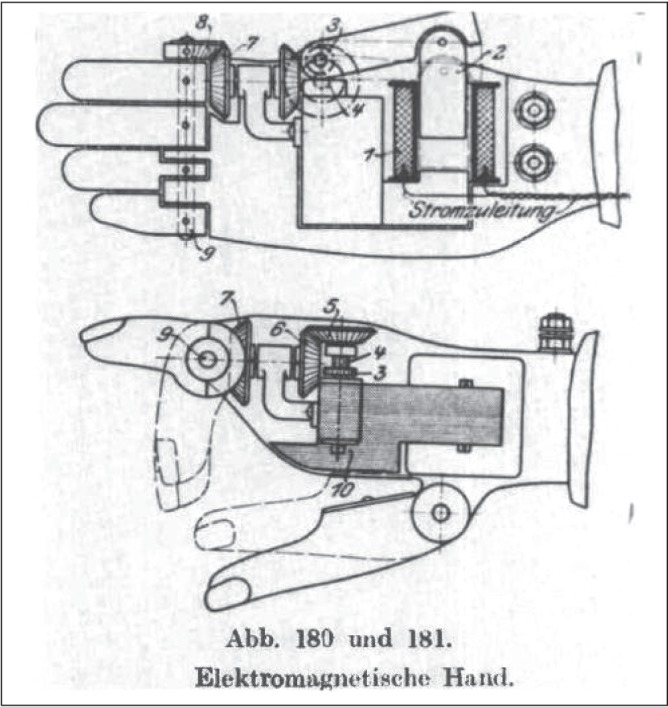
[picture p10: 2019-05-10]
docs/dylan/Onderzoeksrapport/images/PrebluftHand_2.jpg

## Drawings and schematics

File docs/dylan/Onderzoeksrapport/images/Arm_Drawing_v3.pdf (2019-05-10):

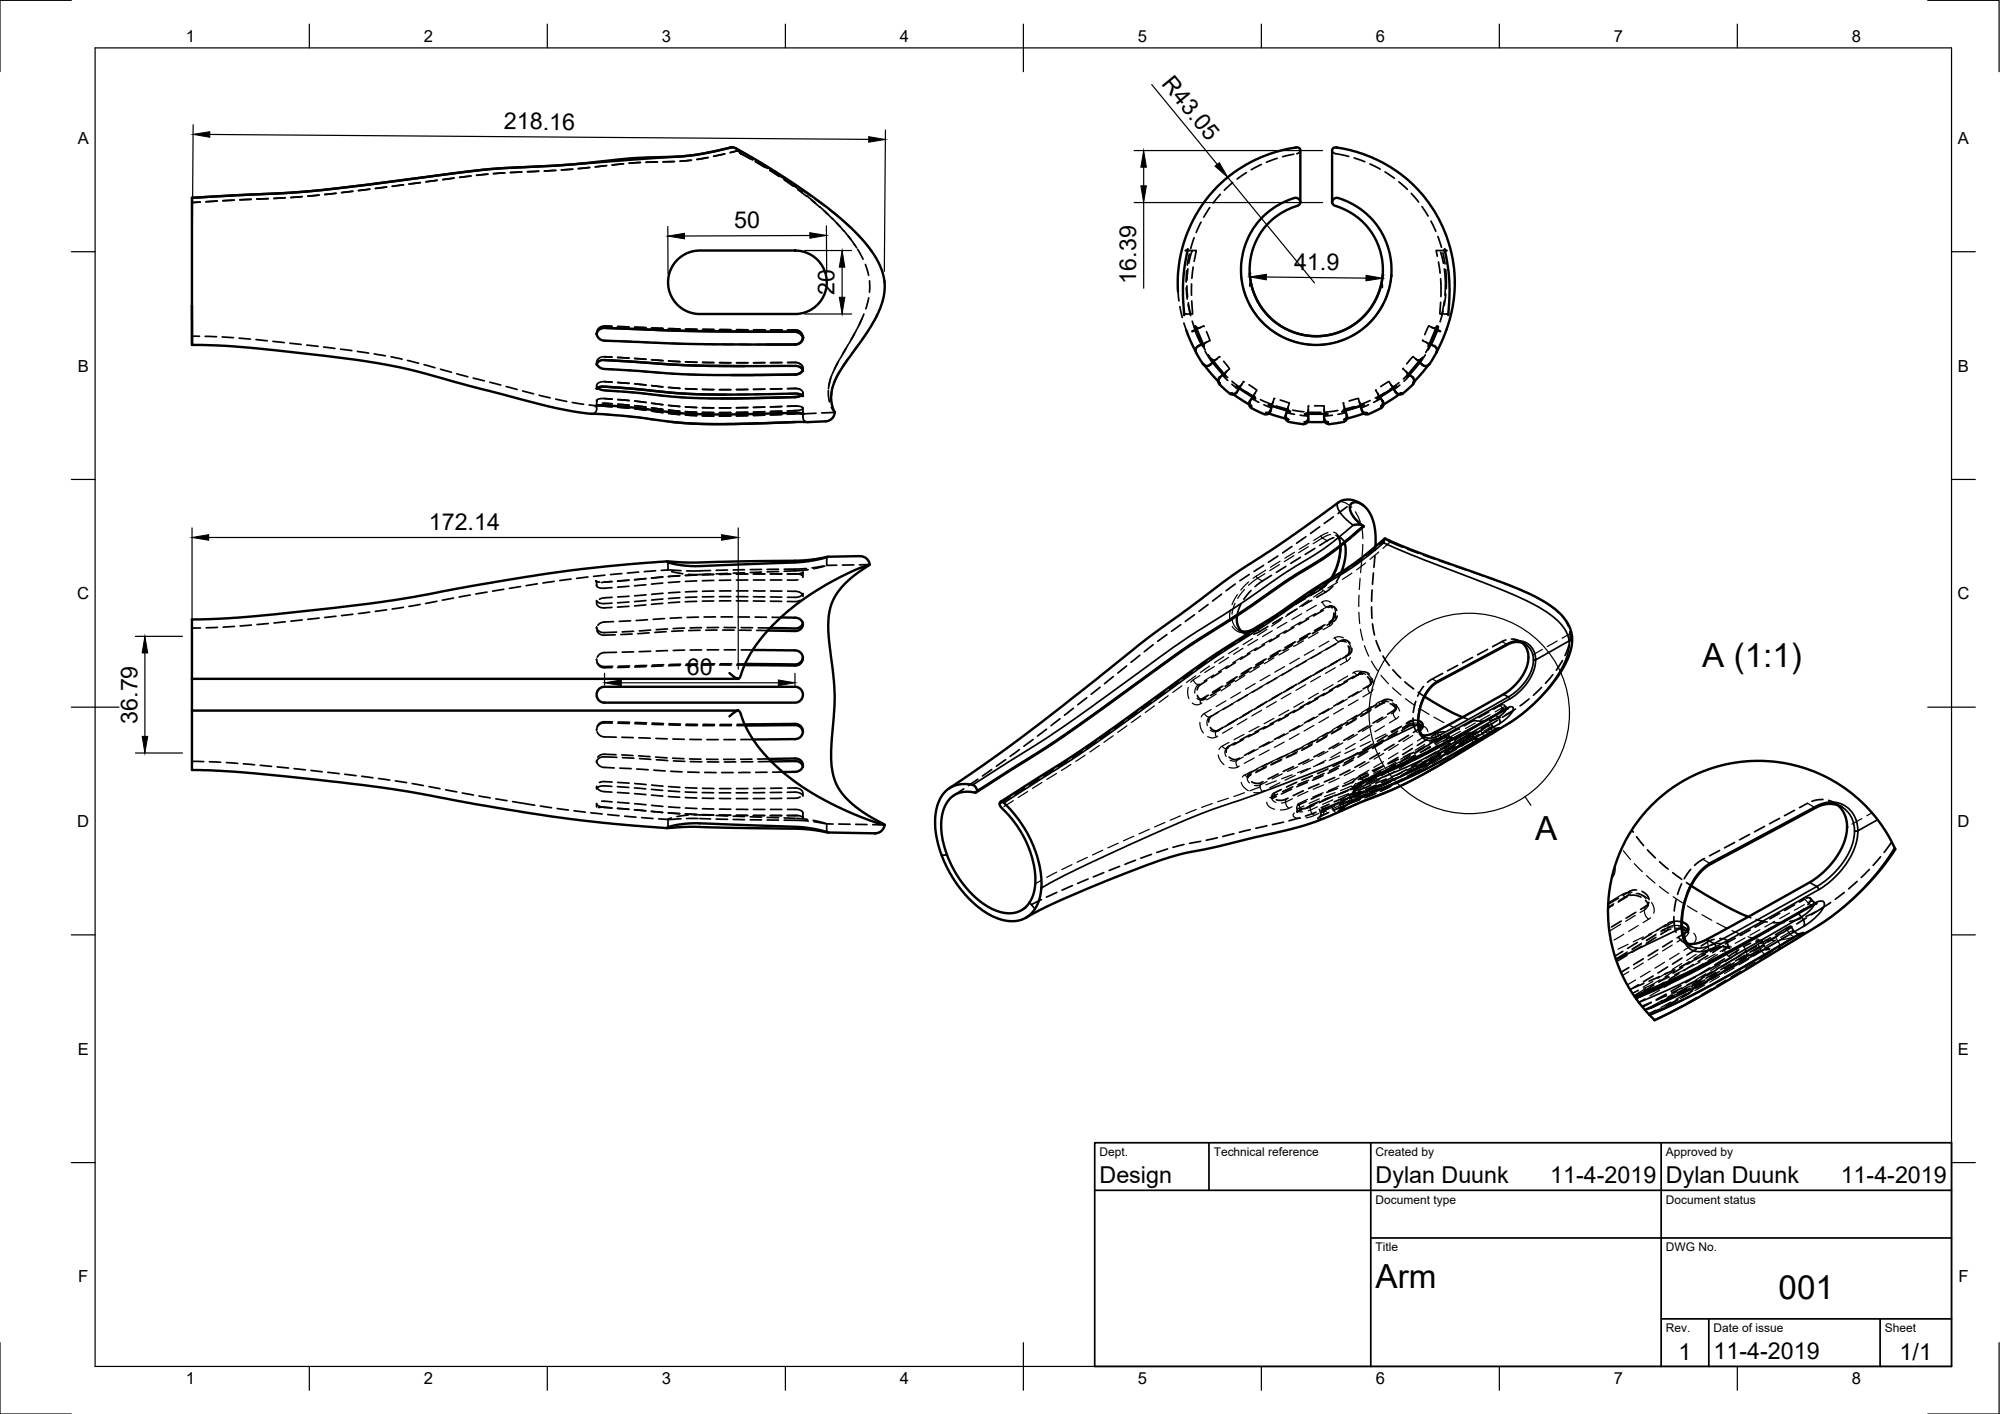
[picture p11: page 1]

Dept. Design | Technical reference | Created by Dylan Duunk 11-4-2019 | Approved by Dylan Duunk 11-4-2019

Document type | Document status

Title | DWG No. 001 Arm

Rev. 1 | Date of issue 11-4-2019 | Sheet 1/1

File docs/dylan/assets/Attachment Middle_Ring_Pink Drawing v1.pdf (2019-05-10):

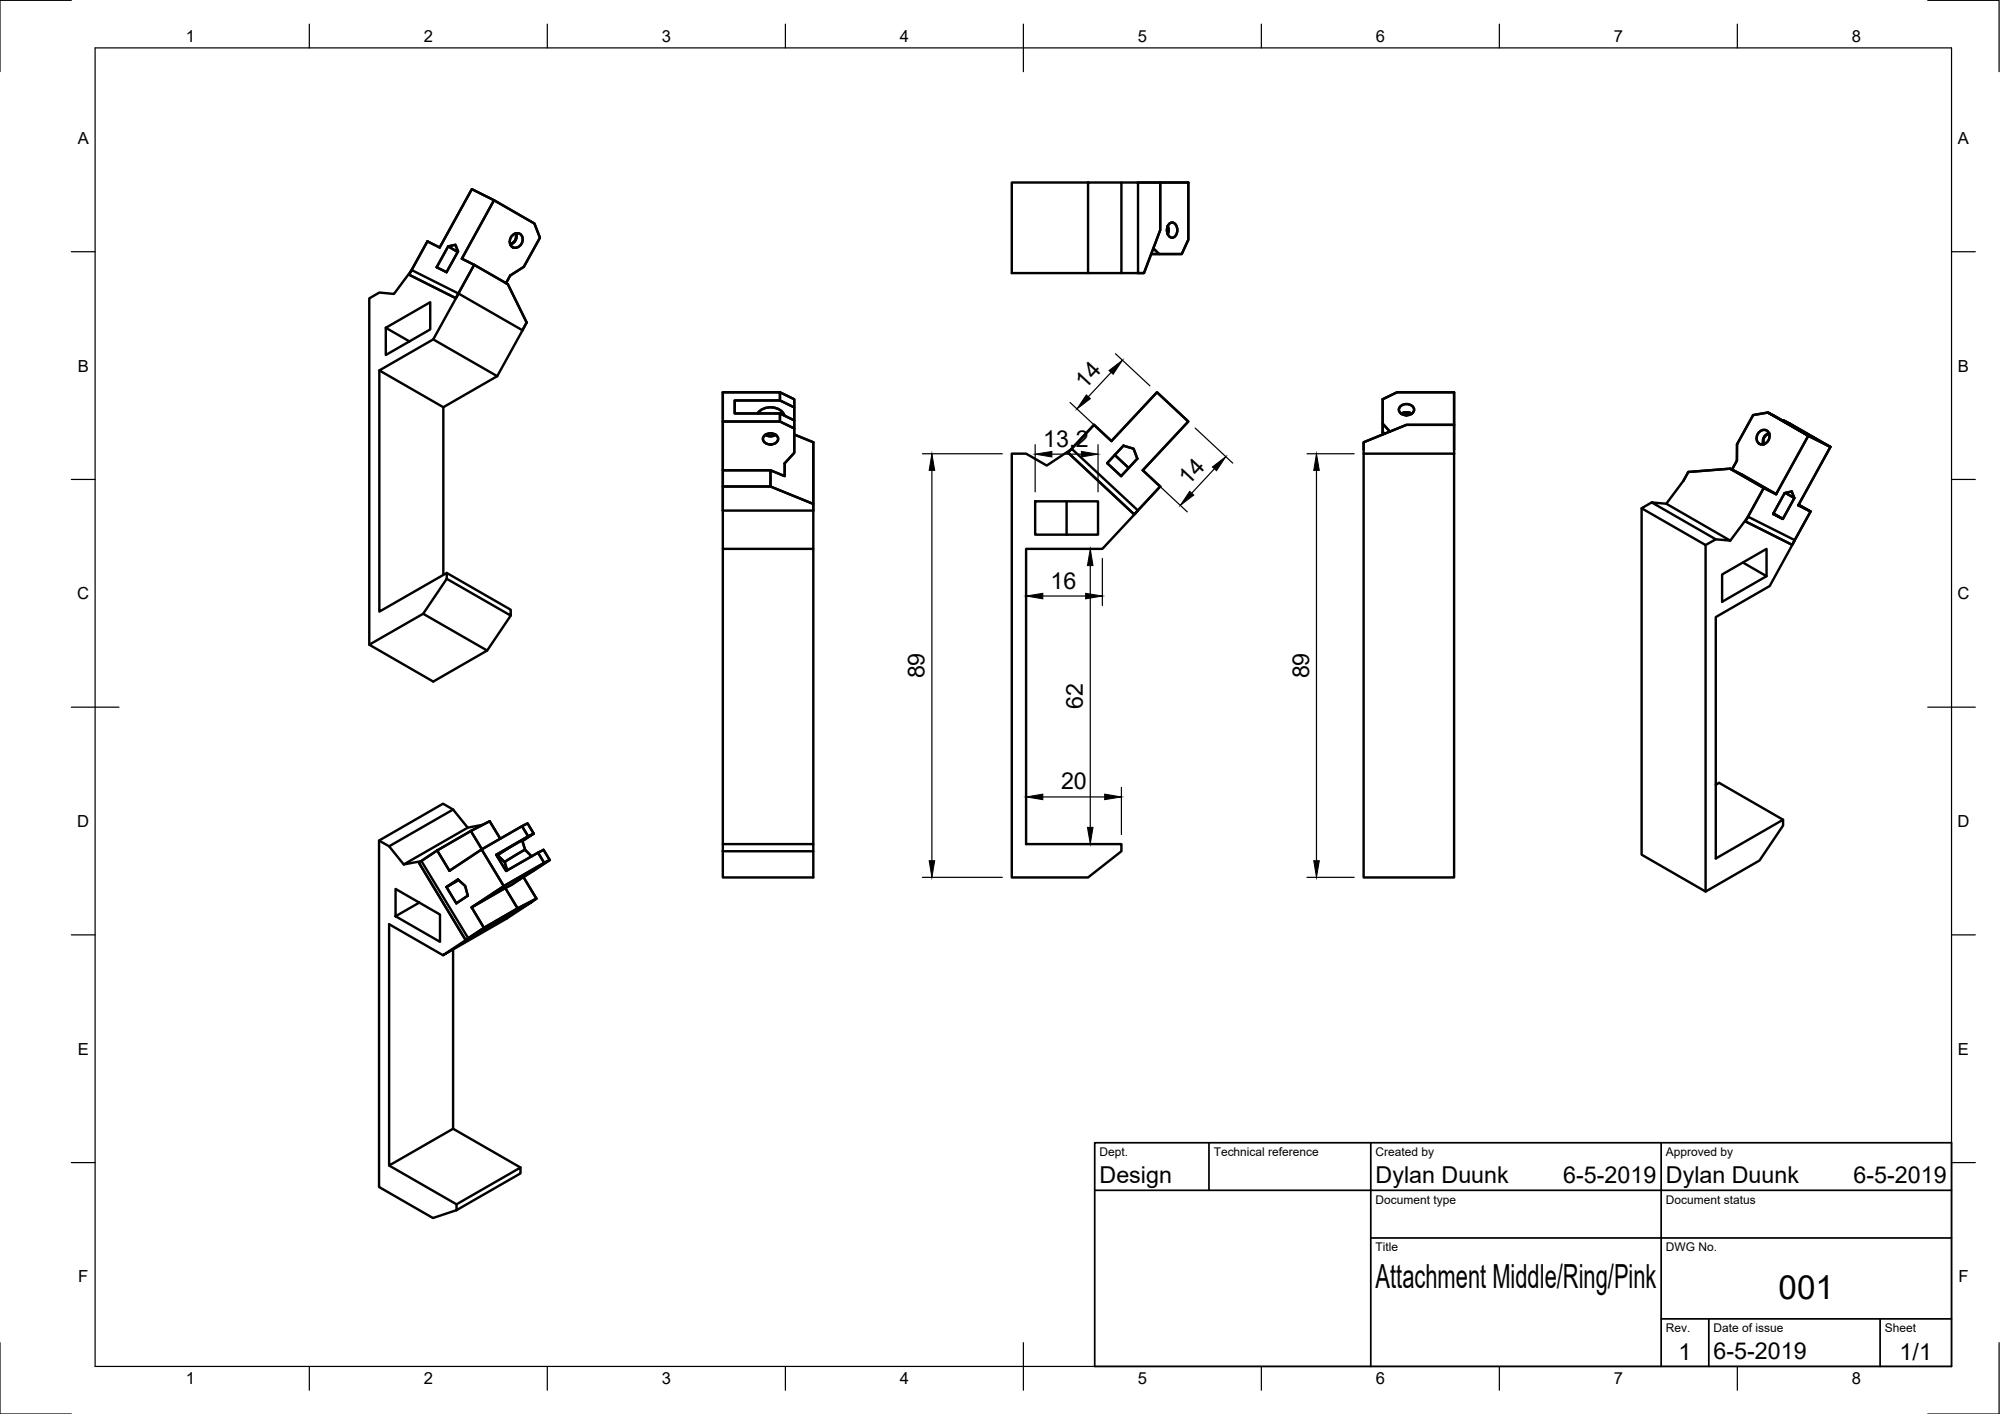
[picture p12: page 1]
Design; Dylan Duunk; Dylan Duunk 62 89

Dept. | Technical reference | Created by 6-5-2019 | Approved by 6-5-2019

Document type | Document status

Title | DWG No. 001 Attachment Middle/Ring/Pink

Rev. 1 | Date of issue 6-5-2019 | Sheet 1/1

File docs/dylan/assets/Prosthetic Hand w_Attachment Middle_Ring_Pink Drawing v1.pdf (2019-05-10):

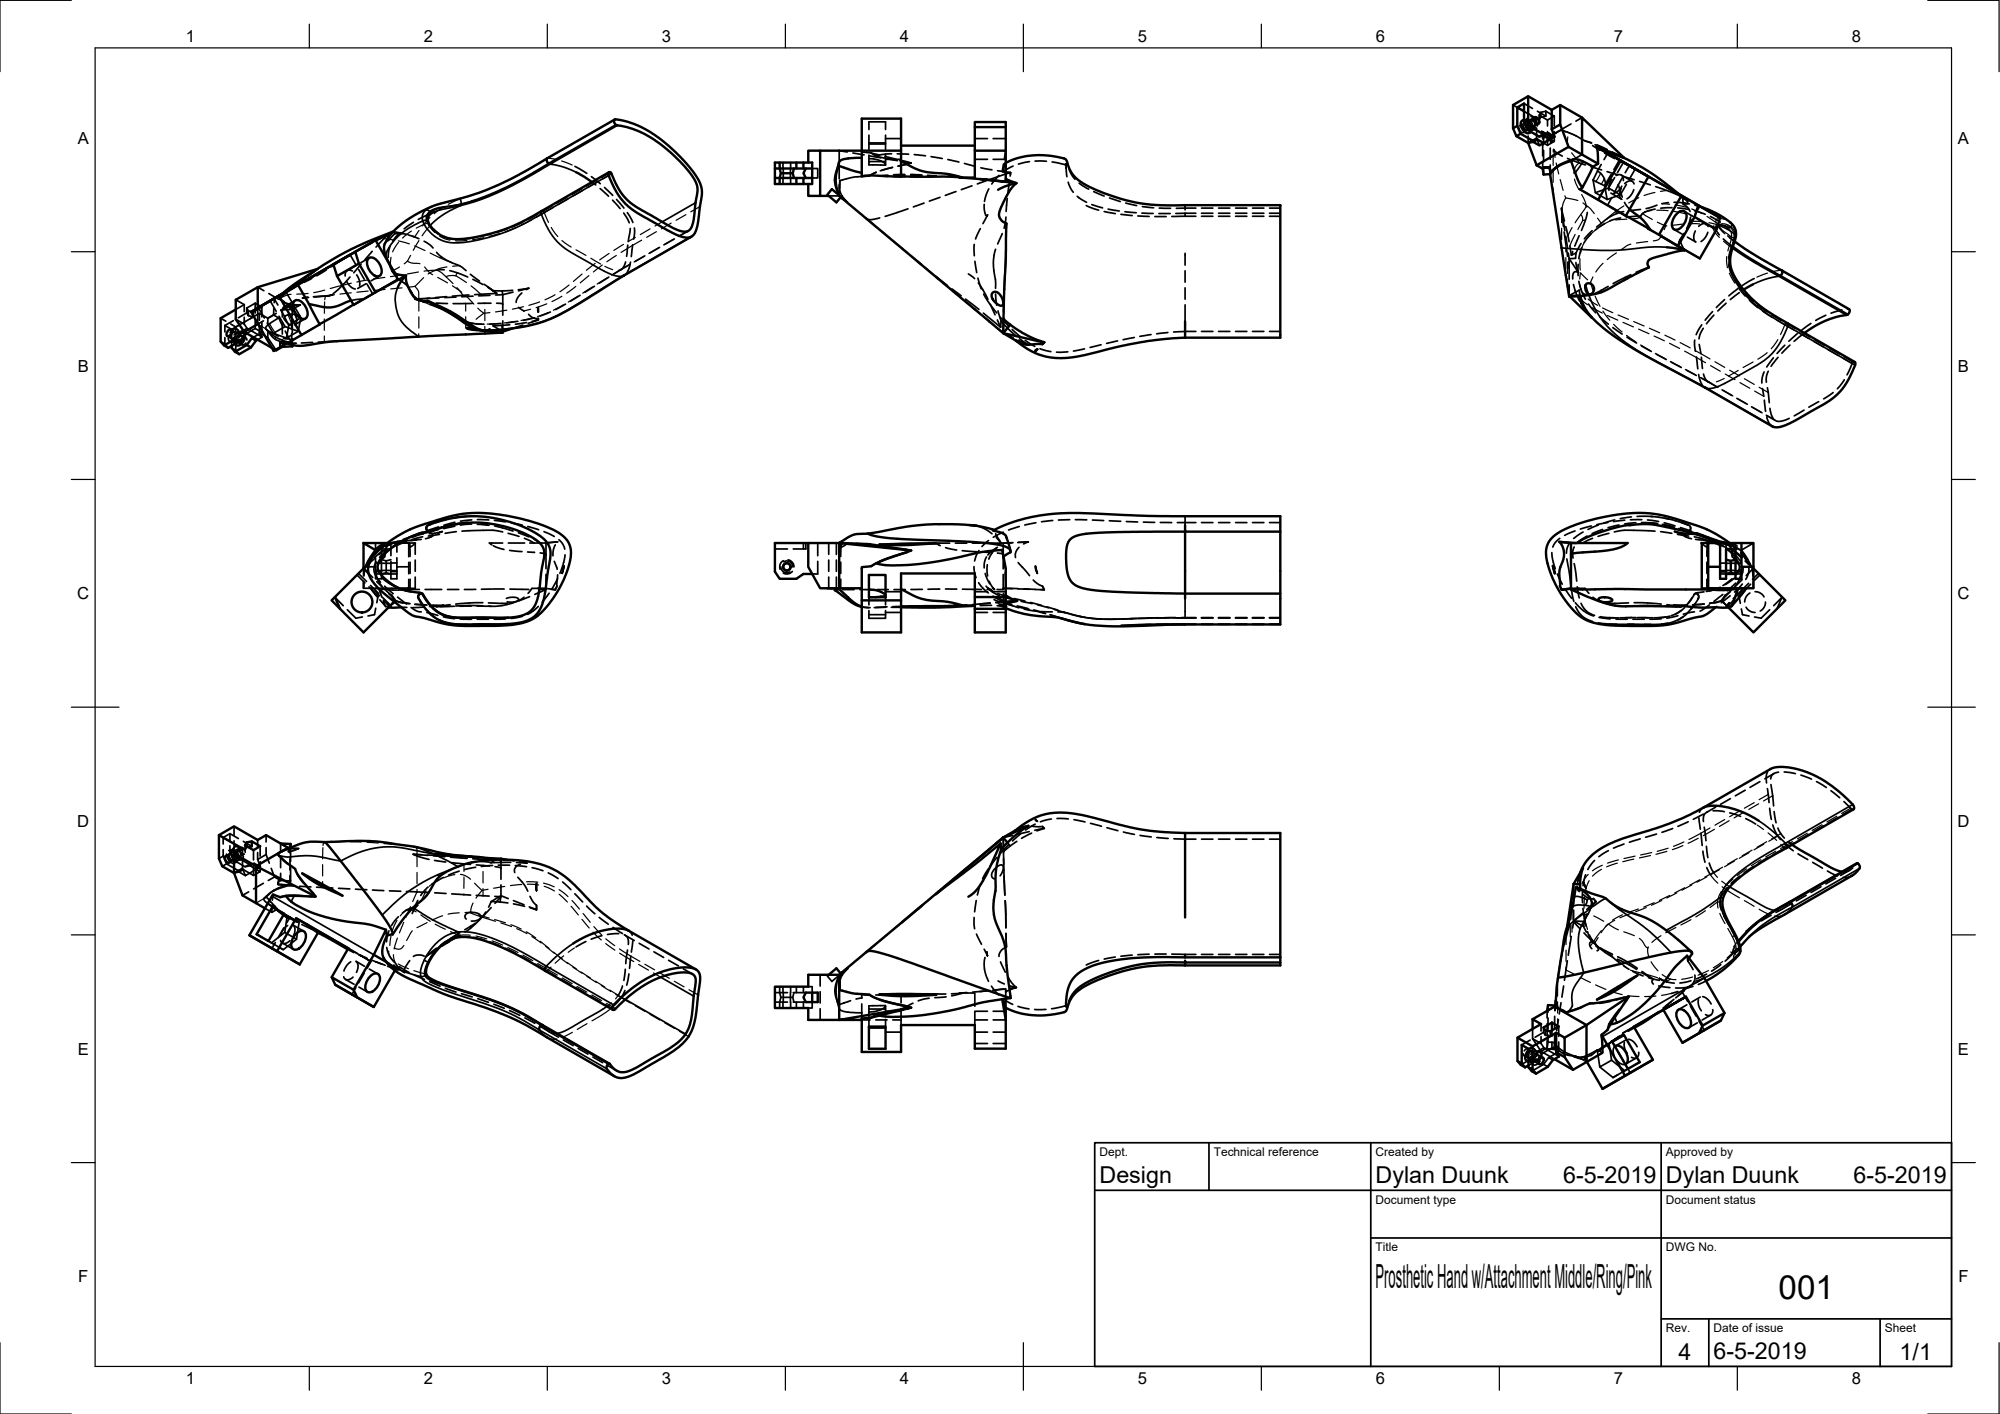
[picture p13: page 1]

Dept. Design | Technical reference | Created by Dylan Duunk 6-5-2019 | Approved by Dylan Duunk 6-5-2019

Document type | Document status

Title | DWG No. 001 Prosthetic Hand w/Attachment Middle/Ring/Pink

Rev. 4 | Date of issue 6-5-2019 | Sheet 1/1

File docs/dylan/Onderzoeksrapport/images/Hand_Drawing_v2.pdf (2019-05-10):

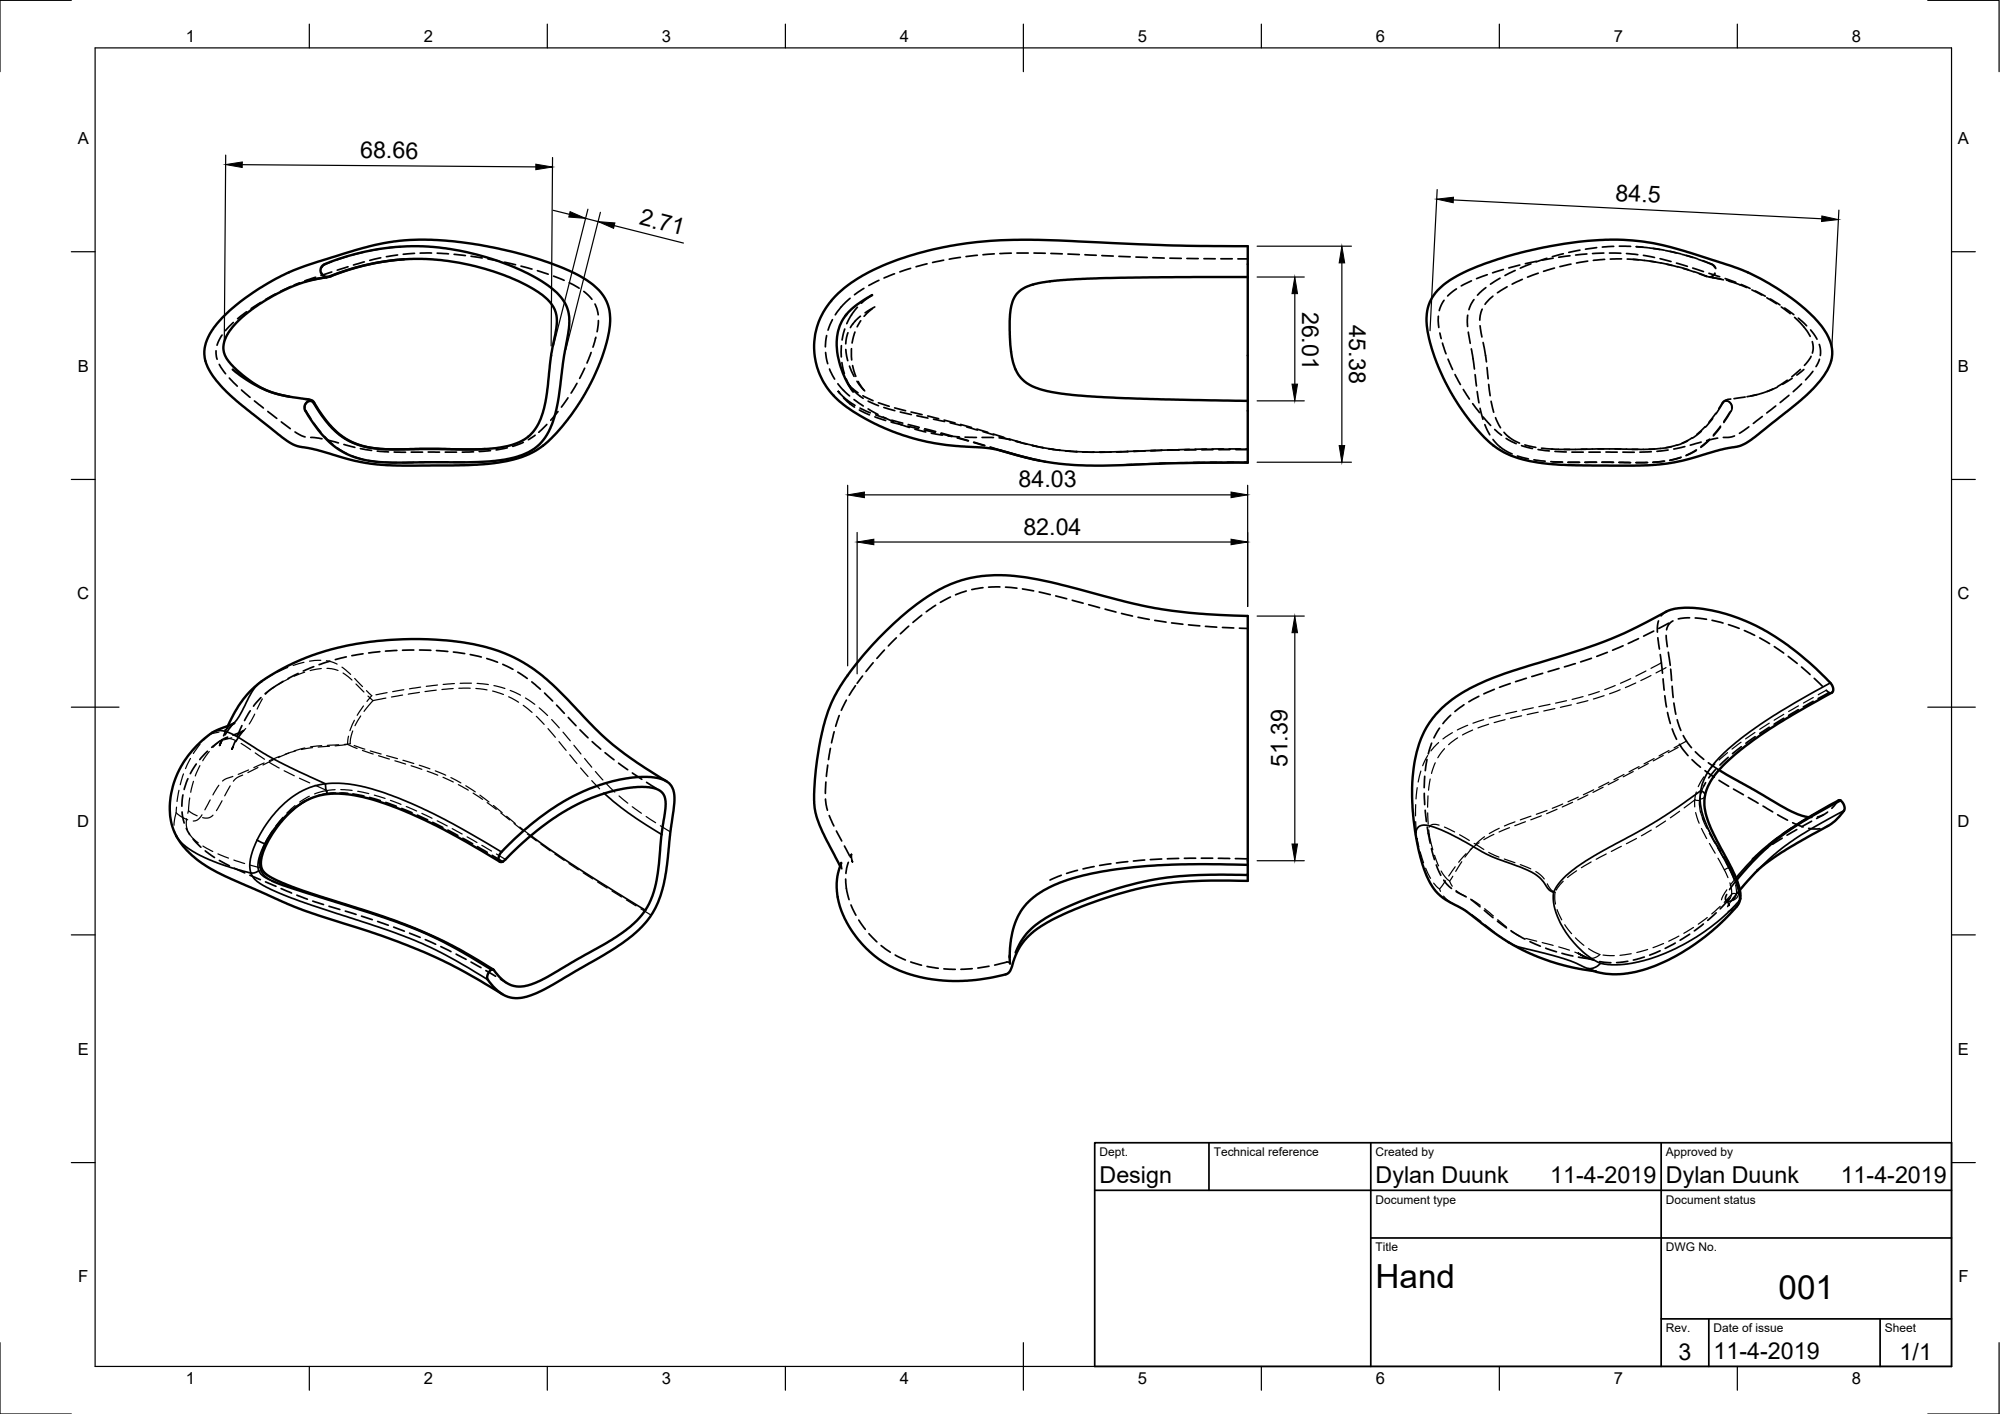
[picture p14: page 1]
Design; Dylan Duunk; Dylan Duunk 26.01 51.39

Dept. | Technical reference | Created by 11-4-2019 | Approved by 11-4-2019

Document type | Document status

Title Hand | DWG No. 001

Rev. 3 | Date of issue 11-4-2019 | Sheet 1/1

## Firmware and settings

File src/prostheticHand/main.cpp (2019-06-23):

#include "main.h"

Hand *hand;

void setup() {
    // Start serial monitor
    Serial.begin(9600);

    // Create a hand
    hand = new Hand();

    // Configure pinMode for shift register
    pinMode(dataPin, OUTPUT);
    pinMode(latchPin, OUTPUT);
    pinMode(clockPin, OUTPUT);
}

void loop() {
    // Handle hand
    hand->service();

    // Handle other things ...
}

void shiftByte(uint8_t val) {
    digitalWrite(latchPin, LOW);
    shiftOut(dataPin, clockPin, MSBFIRST, val);
    digitalWrite(latchPin, HIGH);
}

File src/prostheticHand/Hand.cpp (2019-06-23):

#include "Hand.h"

// Silly translation layer by lack of std::function
void Hand_onPlayPressed(void *self) { ((Hand *)self)->onPlayPressed(); }
void Hand_onPausePressed(void *self) { ((Hand *)self)->onPausePressed(); }
void Hand_onStopPressed(void *self) { ((Hand *)self)->onStopPressed(); }
void Hand_onNextPressed(void *self) { ((Hand *)self)->onNextPressed(); }
void Hand_onPrevPressed(void *self) { ((Hand *)self)->onPrevPressed(); }
void Hand_onRelease(void *self, unsigned long duration) { ((Hand *)self)->onRelease(duration); }

void Hand::onPlayPressed() {
    this->write(this->gestures[this->activeGesture]);
}

/** TODO */
void Hand::onPausePressed() {
    Serial.println("Pause!");
    Serial.println(this->activeGesture);
}

/** TODO */
void Hand::onStopPressed() {
    Serial.println("Stop!");
    // this->write(0);
}

void Hand::onNextPressed() {
    if (!this->gestures[++(this->activeGesture)].name)
        this->activeGesture = 1; // Make sure we skip the NULL value
}

void Hand::onPrevPressed() {
    if (!this->gestures[--(this->activeGesture)].name)
        this->activeGesture = this->gestureSize - 2; // Make sure we skip the NULL value
}

void Hand::onRelease(unsigned long duration) {
    Serial.print("Button was pressed for ");
    Serial.print(duration);
    Serial.println(" ms");
}

Hand::Hand() {
    // Attach servos
    for (int i = 0; i < FingerName::Count; i++) {
        this->fingers[i].servo.attach(this->beginServoPin + i);
    }
}

void Hand::service(void) {
    for (Button *btn = this->buttons; btn->pin; btn++) {
        btn->service(this);
    }

    for (int i = 0; i < FingerName::Count; i++) {
        this->fingers[i].sensors[i].service(this->gestures[this->activeGesture].rotation[i]);
    }
}

void Hand::write(Gesture &gesture) {
    Serial.print("Applying gesture ");
    Serial.println(gesture.name);

    for (int i = 0; i < FingerName::Count; i++) {
        this->fingers[i].servo.write(gesture.rotation[i]);
        delay(500); // Add a delay to prevent finger collision
    }
}

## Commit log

2019-03-11 add research on sensors
2019-03-15 Finished material research in documentation
    -Finished material research in documentation
    - Todo: research comfort
2019-05-27 Removed design folder and moved assets to a dedicated folder
    [PI3_b89ca994-5507-4459-9dc8-5f4939a639a9.stl]
2019-05-27 Rewrote servoTest.ino in c++ format
2019-06-03 Added a button for each finger
2019-06-03 Added Button struct for less code
2019-06-04 Removed unused code
    [Hardware.fzz]
2019-06-19 Rewrote Button functionality w/Callbacks
2019-06-23 Added Force sensor support
